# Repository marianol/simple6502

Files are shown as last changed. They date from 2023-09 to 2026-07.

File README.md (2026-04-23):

# simple6502

My own take on a simple 6502 single board computer, inspired on Garth Wilson's excellent 6502 Primer, Daryl Rictor, Ben Eater, and my own beautiful C=64 and all the classic 8-bit computers of the late 70s early 80s.

This project exists because of scope creep on my YAsixfive02 project, which is in its 10000 iteration. Which I don't think will ever end.

## Organization

The project is organized as follows:

- /hardware
    - /simple6502 The SBC computer motherboard a.k.a The Project
    - /IO_Card A 6522 IO card with 2 VIAs
    - /protoCard A protoboard card for the simple6502 to build your projects
    - /6502motherboard An untested but complete card connector backplane motherboard. I decided to abandon this in favor of the SBC, i may pick it up later
    - /schematics PDF schematics and renders
    - /gallery images of the completed PCBs
    - /3dmodels Kicad 3D models
- /firmware
    - BIOS and ROM for the simple6502, check the ReadMe
- /docs
    - docs will be here for now only datasheets 

## Design

The goal is to build a simple 6502 SBC with RAM, ROM, IO decoding and a serial interface. An expansion  bus will carry all the address, data and supporting lines to allow adding IO and other hardware expansions. The PCB will be kept at 100x100mm to reduce cost.

For the serial interface I settled on the Motorola 68B50 ACIA, just because I had one lying around. This forced using a 1.8432MHz clock that drives both the CPU and the ACIA. I added a header for an FTDI card to convert the TTL serial to USB. The ACIA is connected to the IO_8 line locating it at 0x7F70 in the memory map.
The jumper J2 next to the header allows you to run the board with the USB 5v rail from the FTDI. IMPORTANT!! This overrides the power switch SW2 and there is no protection built into the board so you should not connect this jumper at the same time as the 5V barrel J7 or the AUX Power header J8.
The bus Slot connectors have pin 27 tied to IO_1 and IO_2 respectively allowing to design expansion cards that can be mapped into memory based on where they are plugged. You still have access to IO_3 to IO_7 in case you want to use those. The Expansion Port J1 is intended to be used with a 40 pin ribbon for ease of development of prototype boards.

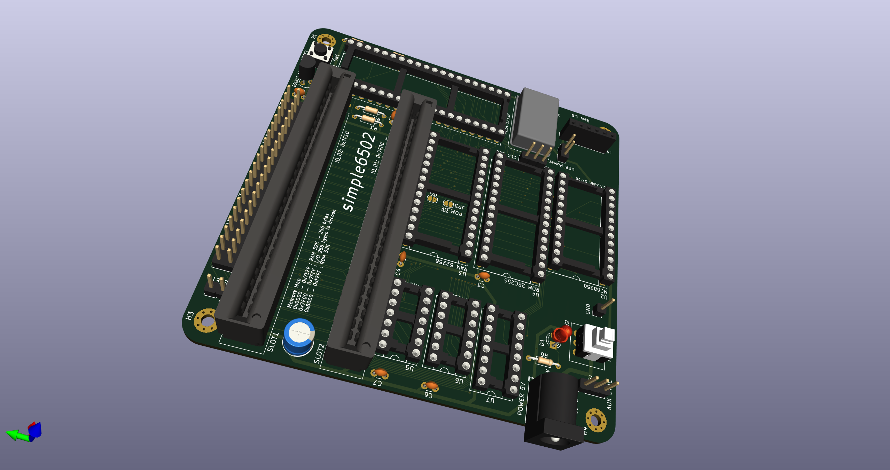
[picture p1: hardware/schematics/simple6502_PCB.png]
Simple6502 Computer


I made the PCBs for Revision 1.6 on PCBWay. 
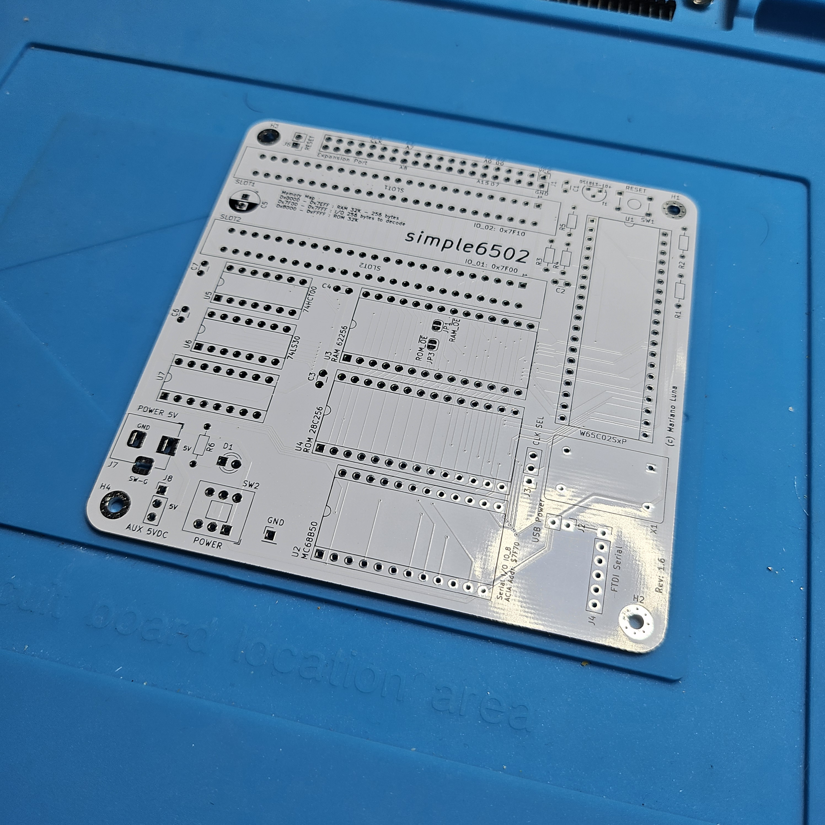
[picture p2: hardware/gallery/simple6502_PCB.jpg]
Simple6502 PCB


## Status

**Revision 1.6:**

- PCB built and tested.
- BIOS 0.0.1 working on Rev 1.6. Minimal BIOS routines to control the ACIA

## Memory Map

Momory Decocing is done using gates for RAM, ROM and IO. IO_CS line is sent to a 3-8 decoder to get 8 individual IO select lines.
IO line  $\overline{IO\textunderscore08}$ is used for the onboard ACIA for serial communication.
IO lines  $\overline{IO\textunderscore01}$ and $\overline{IO\textunderscore02}$ are sent to pin 27 of Slot 1 and 2 respectively. This allows cards that use this pin to get mapped to the memory based on the Slot they are inserted.

I should have mapped some IO on Zero Page for ease of programming and fast IO, but that is left for another revision, since is too convoluted with gates and better suited for a PAL/GAL. 

### Address Space

- 0x0000 - 0x7EFF : RAM 32K - 256 bytes (31.75k)
- 0x7F00 - 0x7F0F : IO_1 > SLOT 1
- 0x7F10 - 0x7F1F : IO_2 > SLOT 2
- 0x7F20 - 0x7F2F : IO_3
- 0x7F30 - 0x7F3F : IO_4
- 0x7F40 - 0x7F4F : IO_5
- 0x7F50 - 0x7F5F : IO_6
- 0x7F60 - 0x7F6F : IO_7
- 0x7F70 - 0x7F7F : IO_8 > ACIA
- 0x7F80 - 0x7FFF : Not Decoded
- 0x8000 - 0xFFFF : ROM (32K)

## Card Connector Design

The card connector is based on the EDAC 395 series. I decided on the 395-50-520-201 which I had from a previous Apple ][ repair.
Exposed in the connector are:

- Address lines A0..A15
- Data lines D0..D7
- Clock $\phi$ 2
- $\overline{IO{\textunderscore}CS}$, $\overline{RAM{\textunderscore}CS}$ , and $\overline{ROM{\textunderscore}CS}$ chip select lines
- $\overline{RD}$ and $\overline{WR}$ 
- $\overline{RESET}$
- Pin 27 is the slot IO select line. For Slot 1 is $\overline{IO\textunderscore01}$ mapping it to 0x7F00, and for Slot 2 is $\overline{IO\textunderscore02}$ mapping it to 0x7F10.
- IO chip select lines $\overline{IO\textunderscore03}$ .. $\overline{IO\textunderscore07}$.
- $\overline{IRQ}$ and $\overline{NMI}$
- VCC and GND, this are set so if you insert a card backwards you will not short them.
- Pins 21, 24, 33, and 34 are only connected between the 2 slots and have no connection to the mainboard 

## Licence

Licenced under CERN Open Hardware licence CERN-OHL-S v2, see CERN-OHL-S-v2.txt

(c) 2023-2024 Mariano Luna. All rights reserved

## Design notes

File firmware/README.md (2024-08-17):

# simple6502 Firmware

This is a BIOS for the simple6502 SBC.

## Requirements

- [x] Serial (ACIA): routines to initialize and manage the serial port.
- [ ] VIA helper routines to interface with a 6522 for I/O
- [x] Memory Monitor: WozMon, why innovate?
- [ ] BASIC: will start with MS Basic from 1976 to be period correct. As a bonus I will have Woz and Gates code in the same ROM
- [ ] Some LOAD/SAVE feature to put binaries in memory though serial/SD for testing. Maybe as an update to WozMon??
- [ ] SPI Interface with VIA (in IO Card)
- [ ] SD Card using SPI

Will come up with some other stuff with 32K I have space for stuff.

## Status

**Version 0.1.0:**

- Tested and working in board rev 1.6
- Features:
  - Wozmon
  - Serial IO Routines

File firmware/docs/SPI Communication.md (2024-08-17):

# SPI Communications

Most of this data comes from:

- <http://elm-chan.org/docs/mmc/mmc_e.html>
- <https://chlazza.nfshost.com/sdcardinfo.html>

## SD Commands

All data sent through the SPI bus are built around the byte - some items may have padding, but the host and card will alwasy send/recieve some multiple of 8 bits.
All command tokens are six bytes long. The card will always respond to every command token with a response token of some kind.

| Command Index | Argument | Response | Data | Abbreviation | Description
| --- | --- | --- | --- | --- | --- | --- |
| CMD0 | None(0) | R1 | No | GO_IDLE_STATE | Software reset.
| CMD1 | None(0) | R1 | No | SEND_OP_COND | Initiate initialization process.
| ACMD41 <sub>*1</sub>  | <sub>*2</sub> | R1 | No | APP_SEND_OP_COND | For only SDC. Initiate initialization process.
| CMD8 | <sub>*3</sub> | R7 | No | SEND_IF_COND | For only SDC V2. Check voltage range.
| CMD9 | None(0) | R1 | Yes | SEND_CSD | Read CSD register.
| CMD10 | None(0) | R1 | Yes | SEND_CID | Read CID register.
| CMD12 | None(0) | R1b | No | STOP_TRANSMISSION | Stop to read data.
| CMD16 | Block | R1 | No | SET_BLOCKLEN | Change R/W block size. 
| | length[31:0] | | | |
| CMD17 | Address[31:0] | R1 | Yes | READ_SINGLE_BLOCK | Read a block.
| CMD18 | Address[31:0] | R1 | Yes | READ_MULTIPLE_BLOCK | Read multiple blocks.
| CMD23 | Number of | R1 | No | SET_BLOCK_COUNT | For only MMC. Define number of blocks to transfer
| | blocks[15:0] | | | | with next multi-block read/write command.
| ACMD23(*1)  | Number of | R1 | No | SET_WR_BLOCK_ERASE_COUNT | For only SDC. Define number of blocks to pre-erase
| | blocks[22:0]  | | | | with next multi-block write command.
| CMD24 | Address[31:0] | R1 | Yes | WRITE_BLOCK | Write a block.
| CMD25 | Address[31:0] | R1 | Yes | WRITE_MULTIPLE_BLOCK | Write multiple blocks.
| CMD55(*1) | None(0) | R1 | No | APP_CMD | Leading command of ACMD\<n> command.
| CMD58 | None(0) | R3 | No | READ_OCR | Read OCR.

*1: ACMD\<n> means a command sequense of CMD55-CM\<n>.
*2: Rsv(0) [31], HCS[30], Rsv(0) [29:0]
*3: Rsv(0) [31:12], Supply Voltage(1) [11:8], Check Pattern(0xAA) [7:0]

## SPI Response

MMC and SDC
There are some command response formats, R1, R2, R3 and R7, depends on the command index. A byte of response, R1, is returned for most commands. The bit field of the R1 response is shown below, the value 0x00 means successful. When any error occured, corresponding status bit in the response will be set. The R3/R7 response (R1 + trailing 32-bit data) is for only CMD58 and CMD8.

Some commands take a time longer than NCR and it responds R1b. It is an R1 response followed by busy flag (DO is driven to low as long as internal process is in progress). The host controller should wait for end of the process until DO goes high (a 0xFF is received).

### R1

| bit 0 | bit 1 | bit 2 | bit 3 | bit 4 | bit 5 | bit 6 | bit 7 |
| --- | --- | --- | --- | --- | --- | --- | --- |
| Always Zero | Parameter Error | Address Error | Erase sequence Error | Command CRC Error | Illegal command | Erase reset | In IDLE state |

### R2

Two bytes in width. The first byte sent is identical to R1. The second byte sent is as follows:

Bit 0: Card is locked > Set when the card is locked by the user. Reset when it is unlocked.
Bit 1: Write protect erase skip | lock/unlock command failed > This status bit has two functions overloaded. It is set when the host attempts to erase a write-protected sector or makes a sequence or password errors during card lock/unlock operation.
Bit 2: Error > A general or an unknown error occurred during the operation.
Bit 3: CC error > Internal card controller error.
Bit 4: Card ECC failed > Card internal ECC was applied but failed to correct the data.
Bit 5: Write protect violation > The command tried to write a write-protected block.
Bit 6: Erase param > An invalid selection for erase, sectors or groups.
Bit 7: out of range | csd overwrite.

### R3

Five bytes in width. The first byte sent is identical to R1. The following four bytes are the contents of the OCR register.

### R7

R7 is 5 bytes long, and the first byte is identical to R1. Following that we have a command version field, a voltage accepted field, and an "echo-back" of the check pattern we sent in the command. Note that if you are using a first generation card, it will only return R1 with the illegal bit command set.

Bit 0-7:   R1 response
Bit 8-11:  Command version
Bit 12-16: Reserved bits
Bit 17-21: Voltage accepted
Bit 22-20: Check pattern

The Voltage accepted pattern is as follows:
0b00000001  Voltage 2.7v to 3.3v
0b00000010  Low Voltage
0b00000100  Reserved
0b00001000  Reserved

Check pattern is an echo of the check pattern

## SD Initialization in SPI mode

<http://elm-chan.org/docs/mmc/mmc_e.html#spiinit>

1. Put thr card in native mode ready for commands, this should be done after
power On or card insertion:

- De-select CS (i.e. make it HIGH)
- Send 10 bytes of 0xFF (i.e. keep MOSI high, toggle CLK 80 times).
  
1. Set SPI mode sending a CMD0 with CS low to reset the card. Since the CMD0 must be sent as a native command, the CRC field must have a valid value.

- Assert CS (set it LOW)
- Send CMD0, then keep reading (by toggling CLK) until a 0x01 response is received

Send a CMD55 (indicates the next byte will be application specific)
Send a CMD41. If the response is not 0 then loop from CMD55 again
Once a zero comes back, the card is ready, send a CMD16 and set block size to 512 bytes

## Block Length

Read and write operations are performed on SD cards in blocks of set lengths. Block length can be set in Standard Capacity SD cards using CMD16 (SET_BLOCKLEN). For SDHC and SDXC cards cards the block length is always set to 512 bytes.

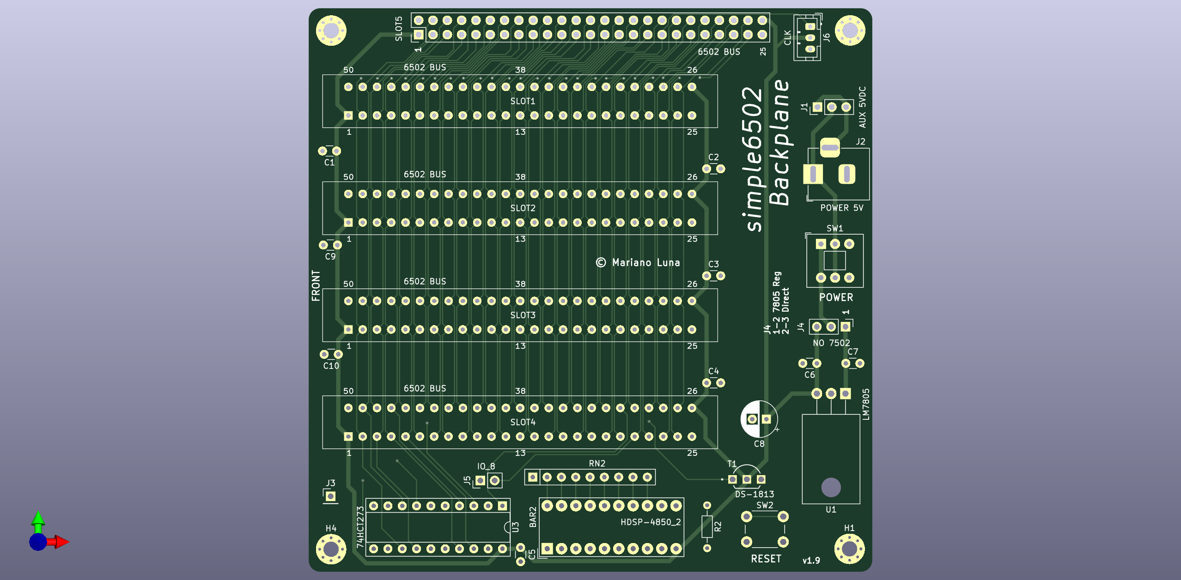
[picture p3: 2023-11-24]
hardware/schematics/6502motherboard_PCB_front_bare.png

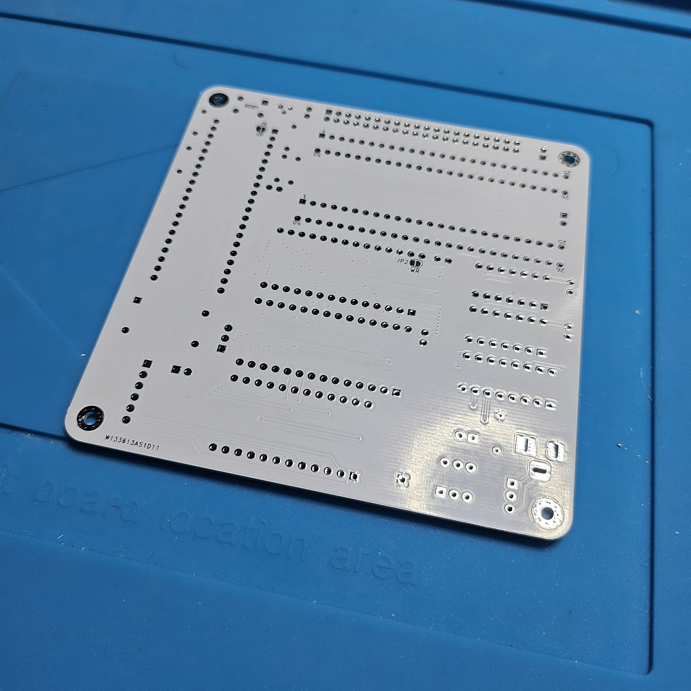
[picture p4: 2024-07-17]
hardware/gallery/simple6502_PCB_back.jpg

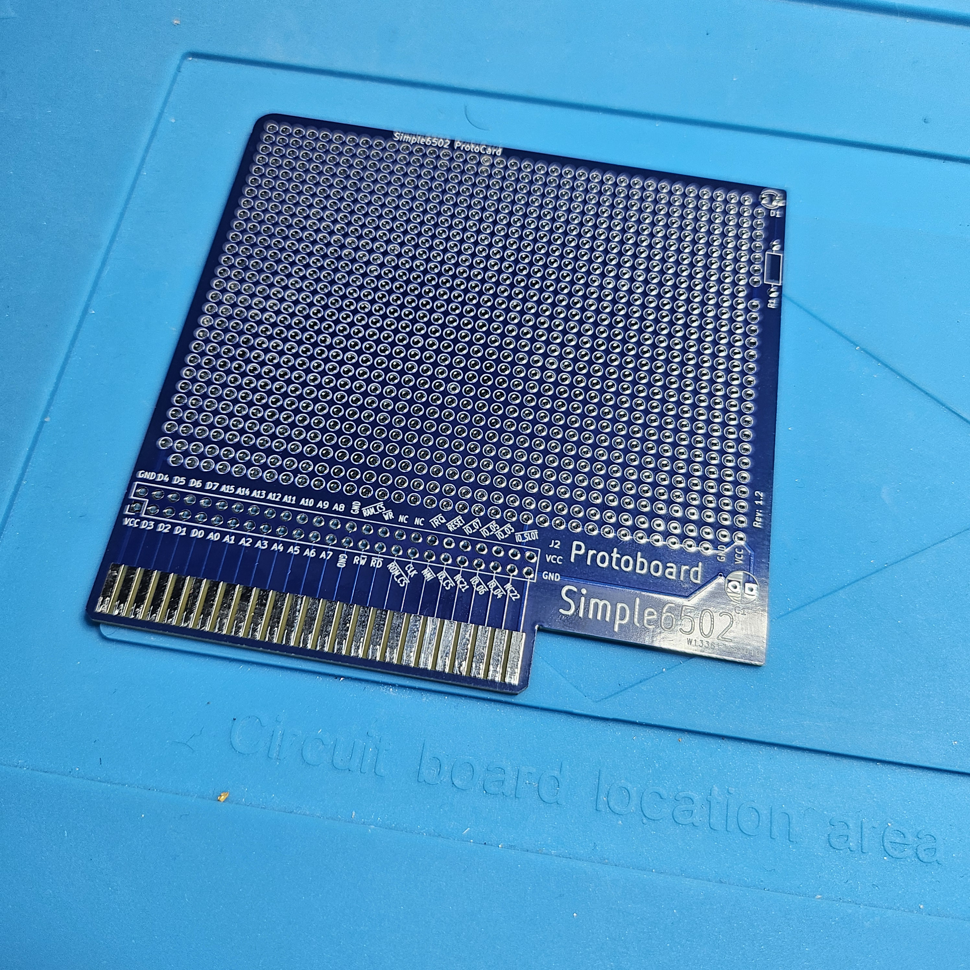
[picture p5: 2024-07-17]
hardware/gallery/protoCard_PCB_front.jpg

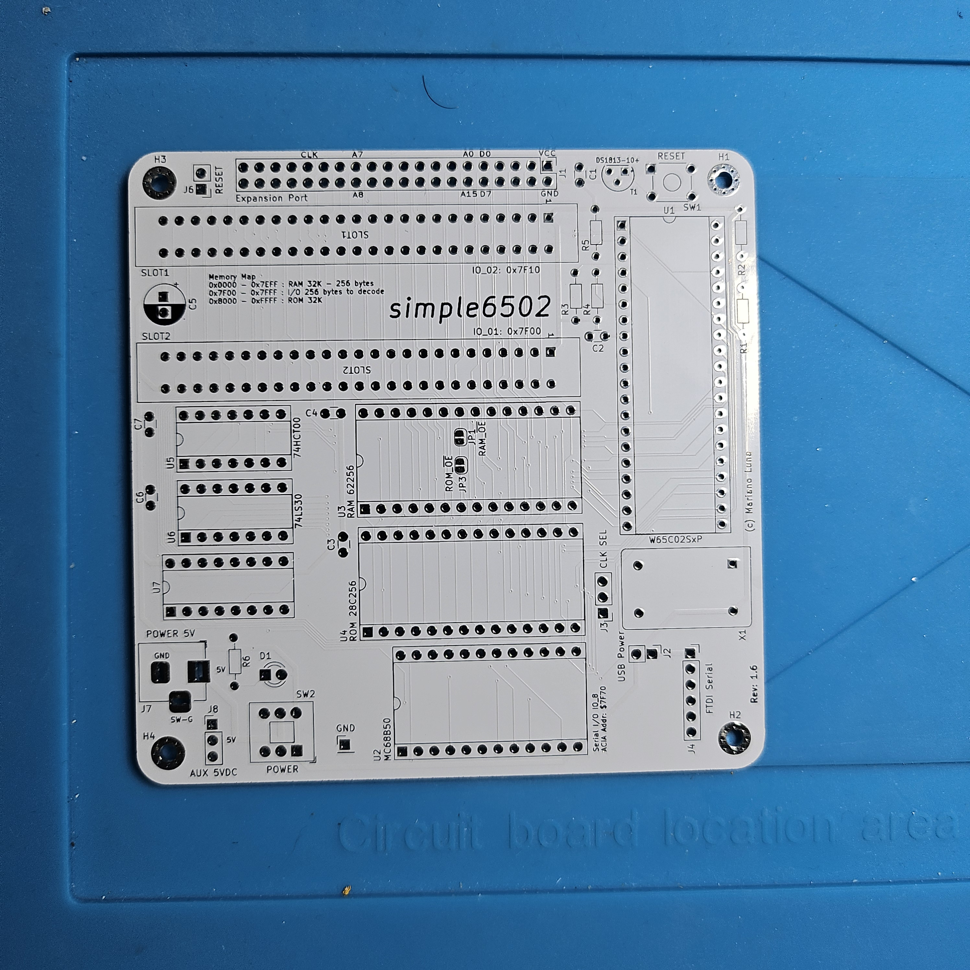
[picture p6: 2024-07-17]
hardware/gallery/simple6502_PCB_front.jpg

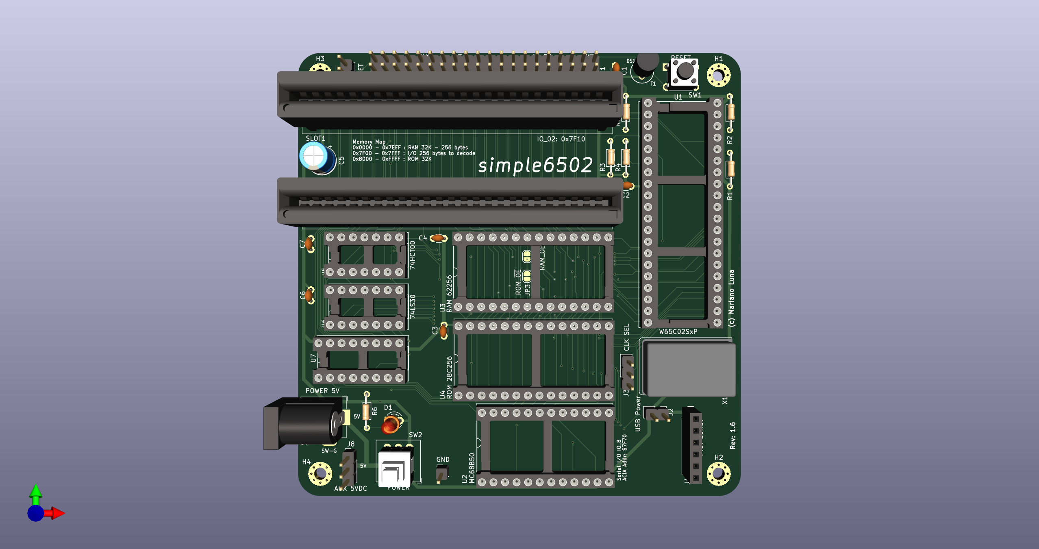
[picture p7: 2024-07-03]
hardware/schematics/simple6502_PCB_front.png

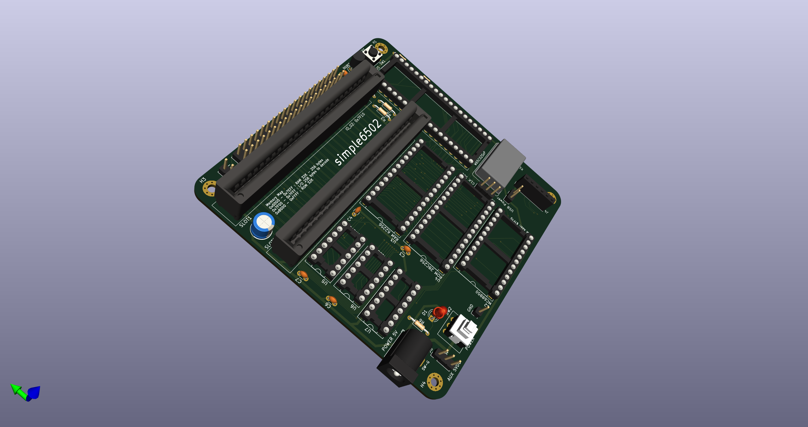
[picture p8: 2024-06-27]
hardware/schematics/simple6502_board.png

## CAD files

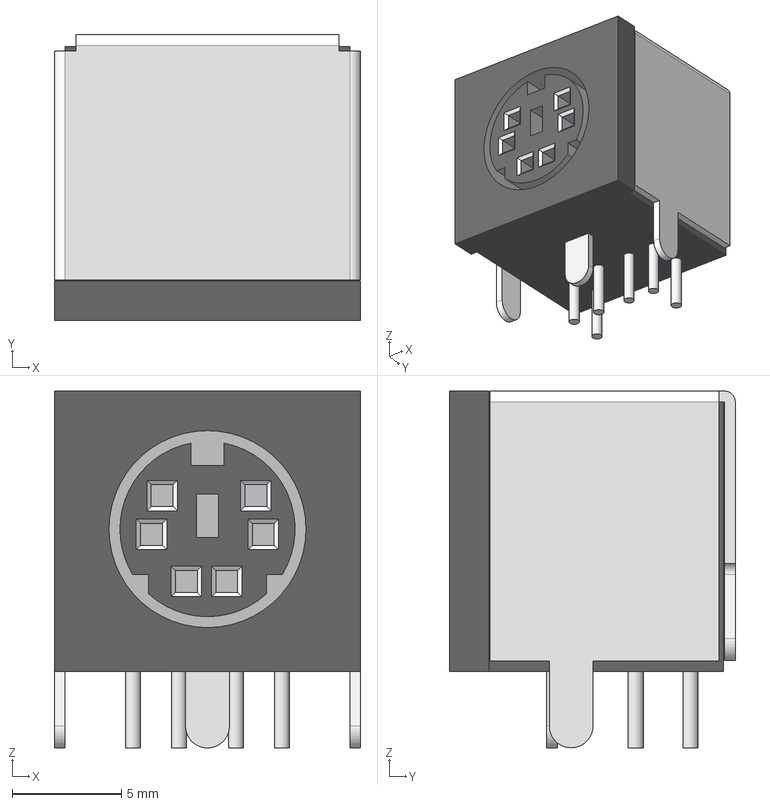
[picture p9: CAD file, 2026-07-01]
hardware/6502_Kicad_Library/3dmodels/Conn_Mini_DIN_round_6_canned.stp
14.0 x 13.1 x 16.3 mm

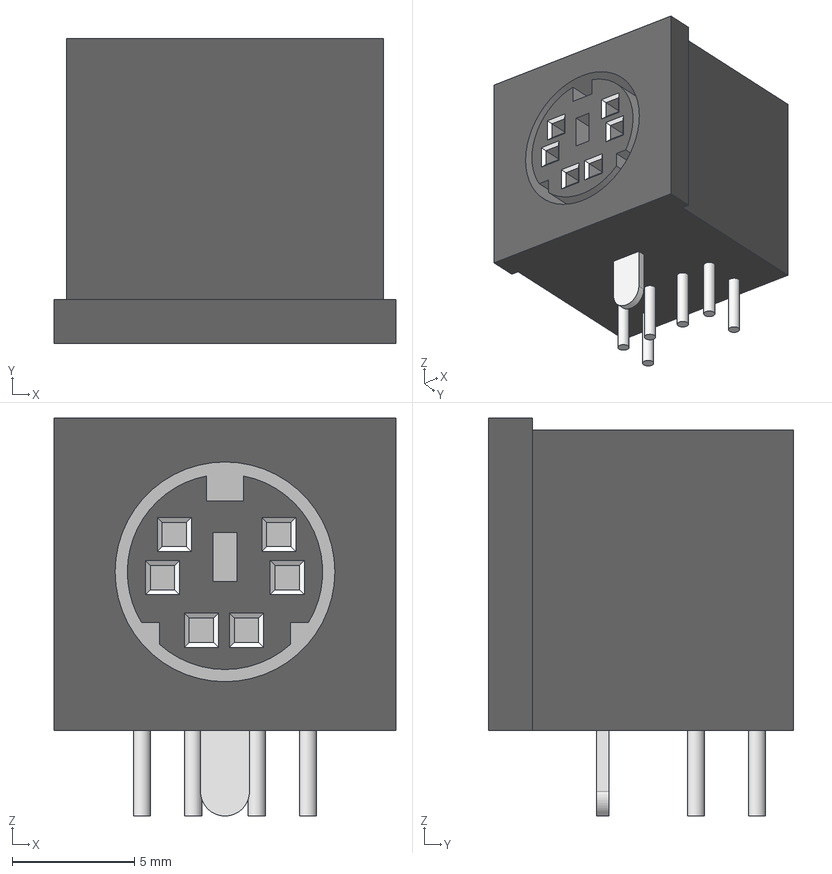
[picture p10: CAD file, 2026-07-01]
hardware/6502_Kicad_Library/3dmodels/Conn_Mini_DIN_round_6.stp
14.0 x 12.5 x 16.3 mm

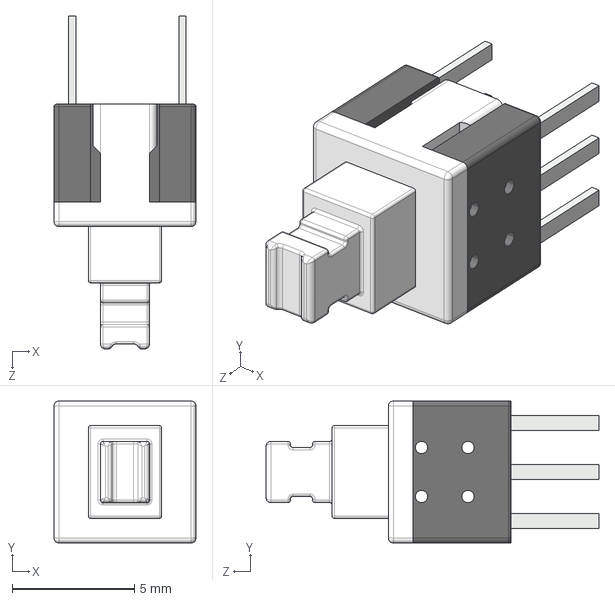
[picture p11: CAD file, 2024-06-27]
hardware/6502_Kicad_Library/3dmodels/5.8x5.8mmSWITCH.STEP
5.80 x 5.80 x 13.6 mm

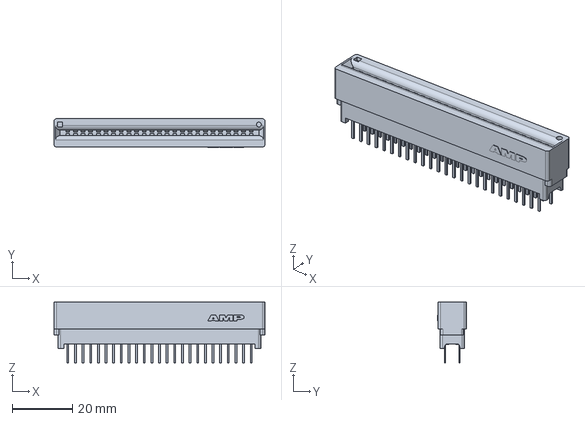
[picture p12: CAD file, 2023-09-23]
hardware/6502_Kicad_Library/3dmodels/CONN 25 POS 2 ROW v2.step
70.1 x 9.47 x 20.2 mm

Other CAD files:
hardware/6502_Kicad_Library/3dmodels/CONN-25POS-2ROW.stl
hardware/6502_Kicad_Library/3dmodels/CONN 25 POS 2 ROW v1.step

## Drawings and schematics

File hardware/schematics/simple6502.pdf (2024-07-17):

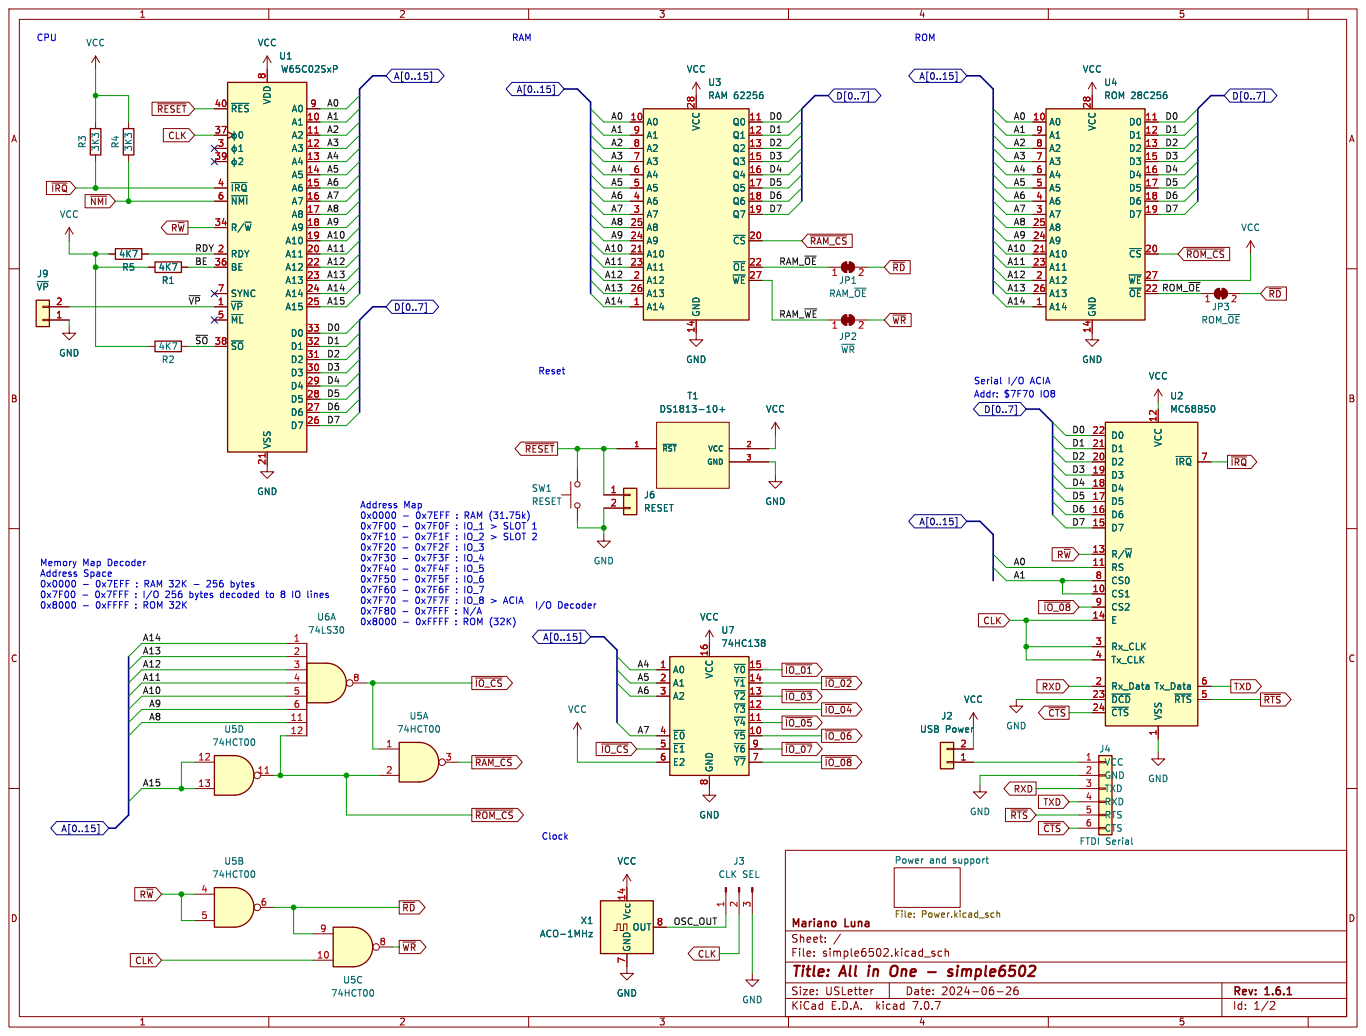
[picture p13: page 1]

Addr: $7F70 IO8 Serial I/O ACIA Clock

I/O Decoder Memory Map Decoder Address Space

0x0000 - 0x7EFF : RAM 32K - 256 bytes 0x7F00 - 0x7FFF : I/O 256 bytes decoded to 8 IO lines 0x8000 - 0xFFFF : ROM 32K

7 OUT X1 8 ACO-1MHz GND GND

Id: 1/2 Title: All in One - simple6502

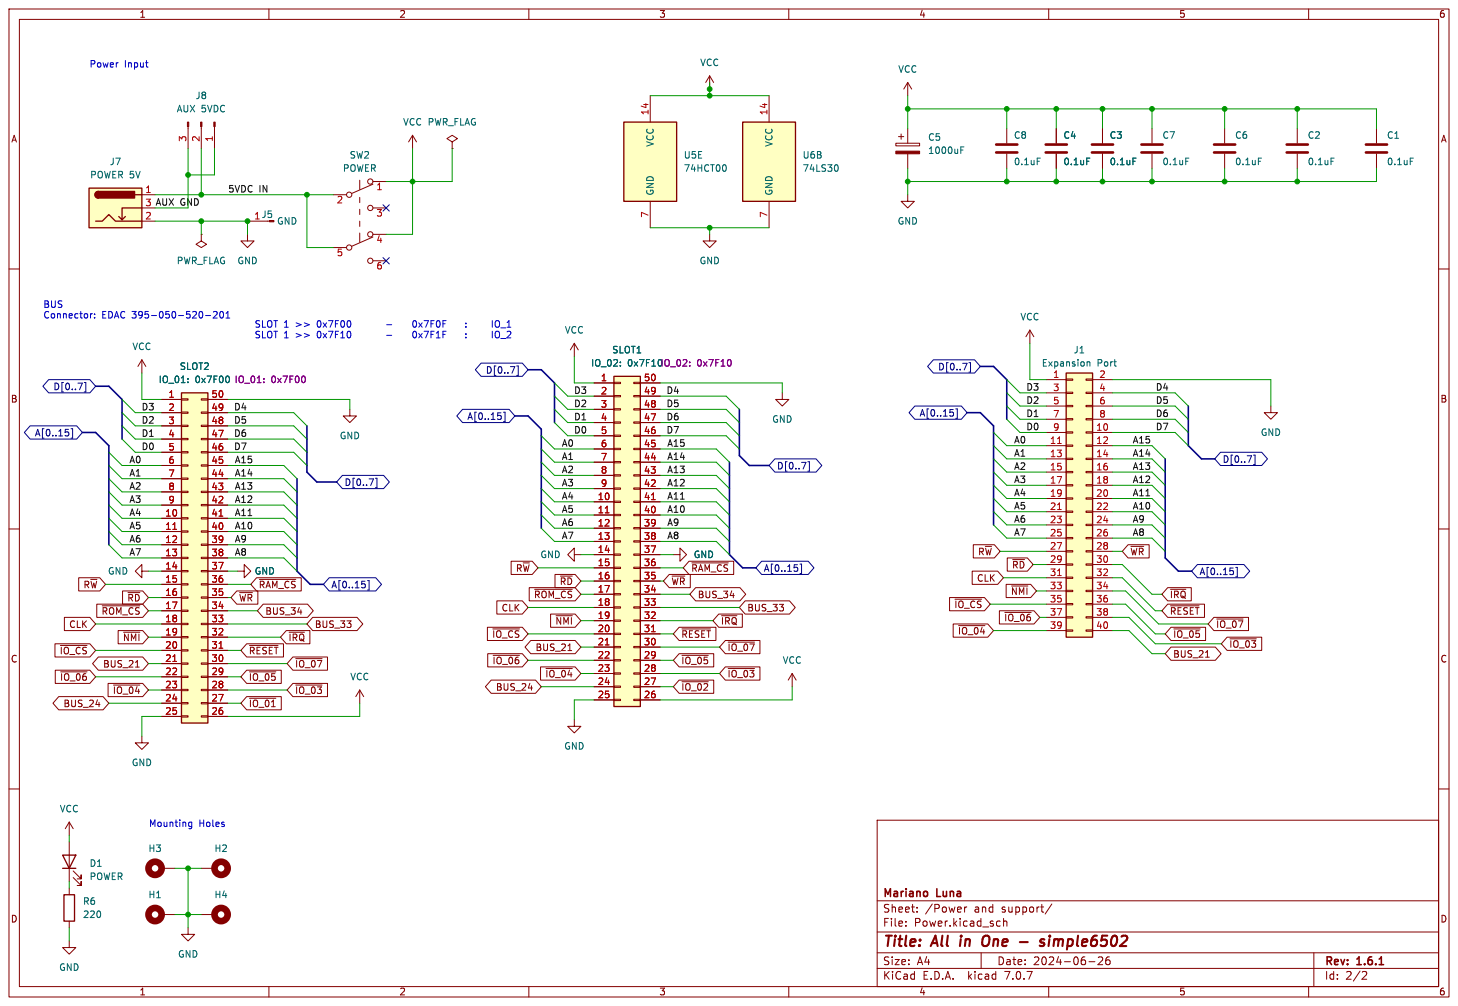
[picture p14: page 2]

J1 Expansion Port VCC GND

Id: 2/2 Title: All in One - simple6502

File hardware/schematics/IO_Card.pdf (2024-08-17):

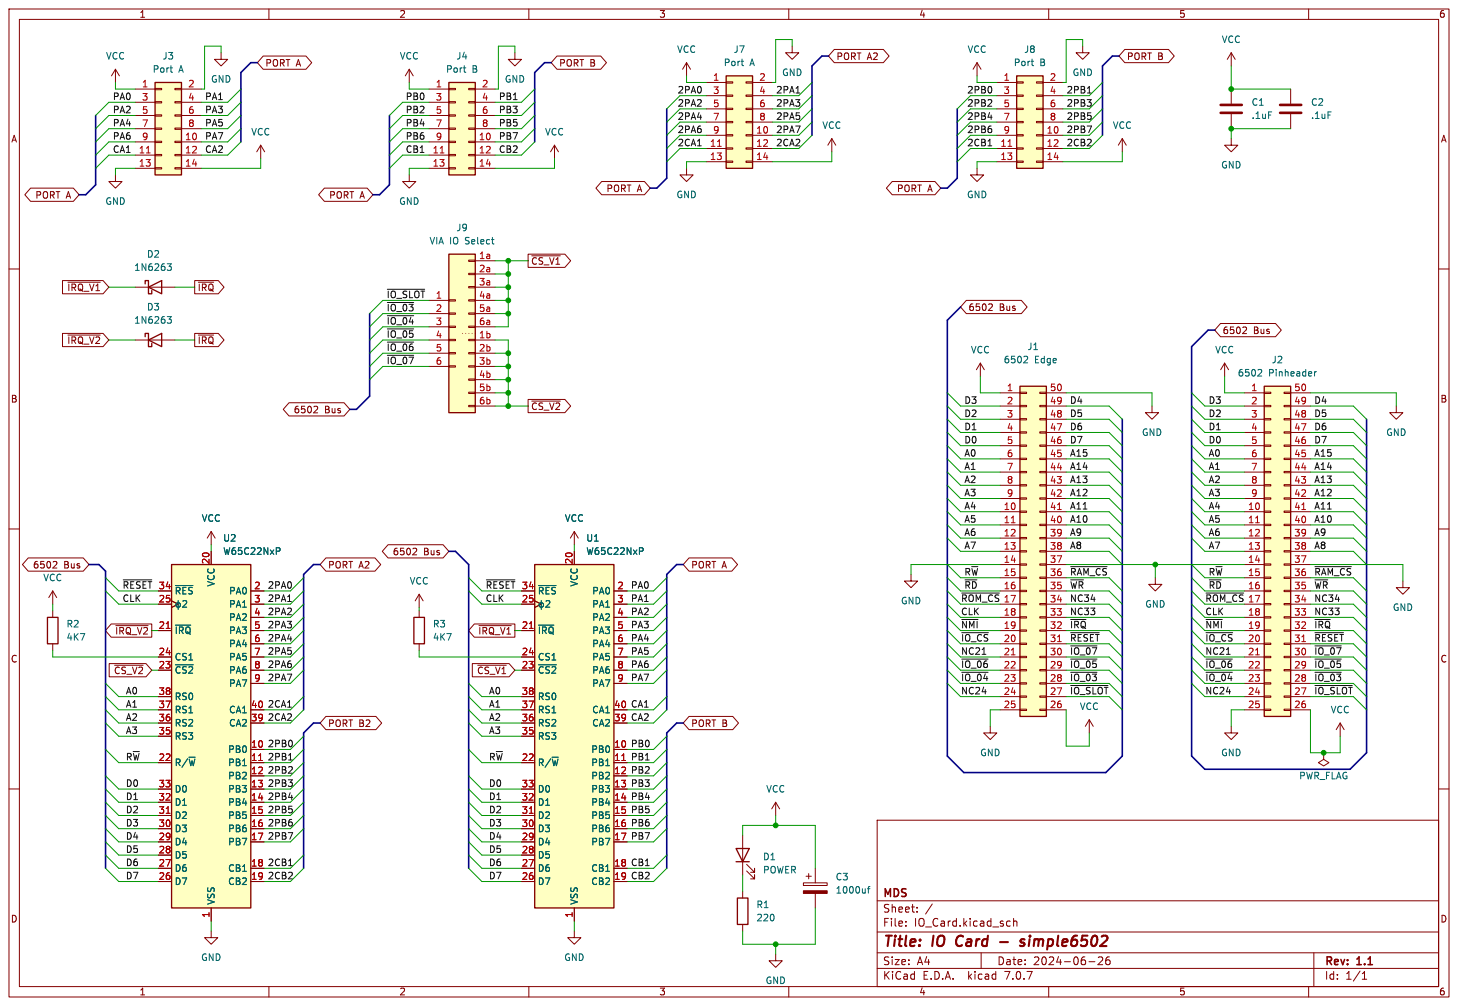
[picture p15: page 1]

Id: 1/1 Title: IO Card - simple6502

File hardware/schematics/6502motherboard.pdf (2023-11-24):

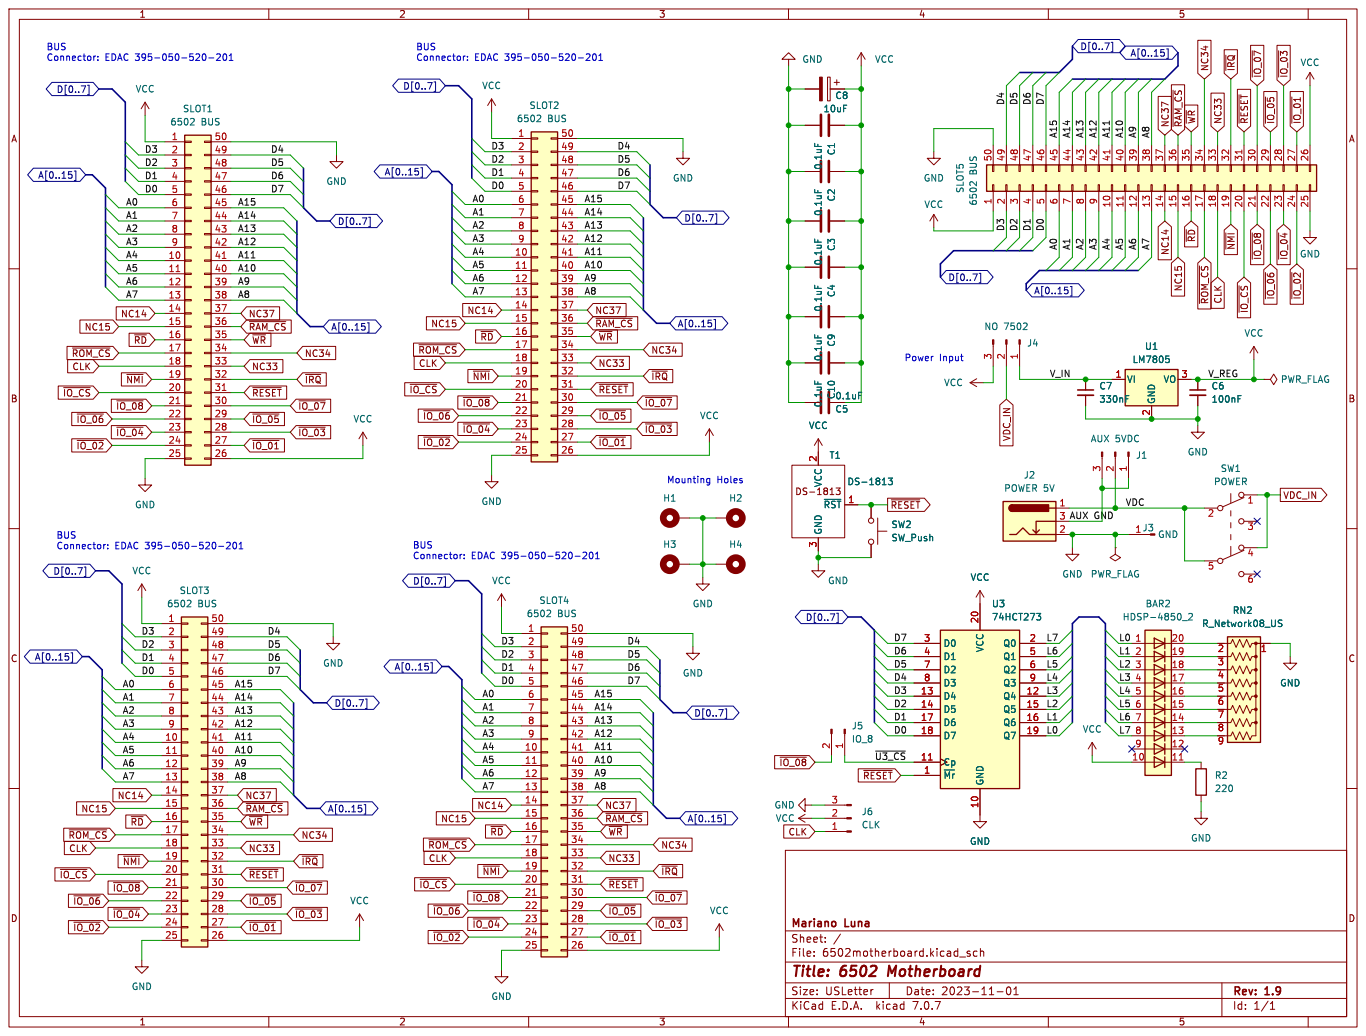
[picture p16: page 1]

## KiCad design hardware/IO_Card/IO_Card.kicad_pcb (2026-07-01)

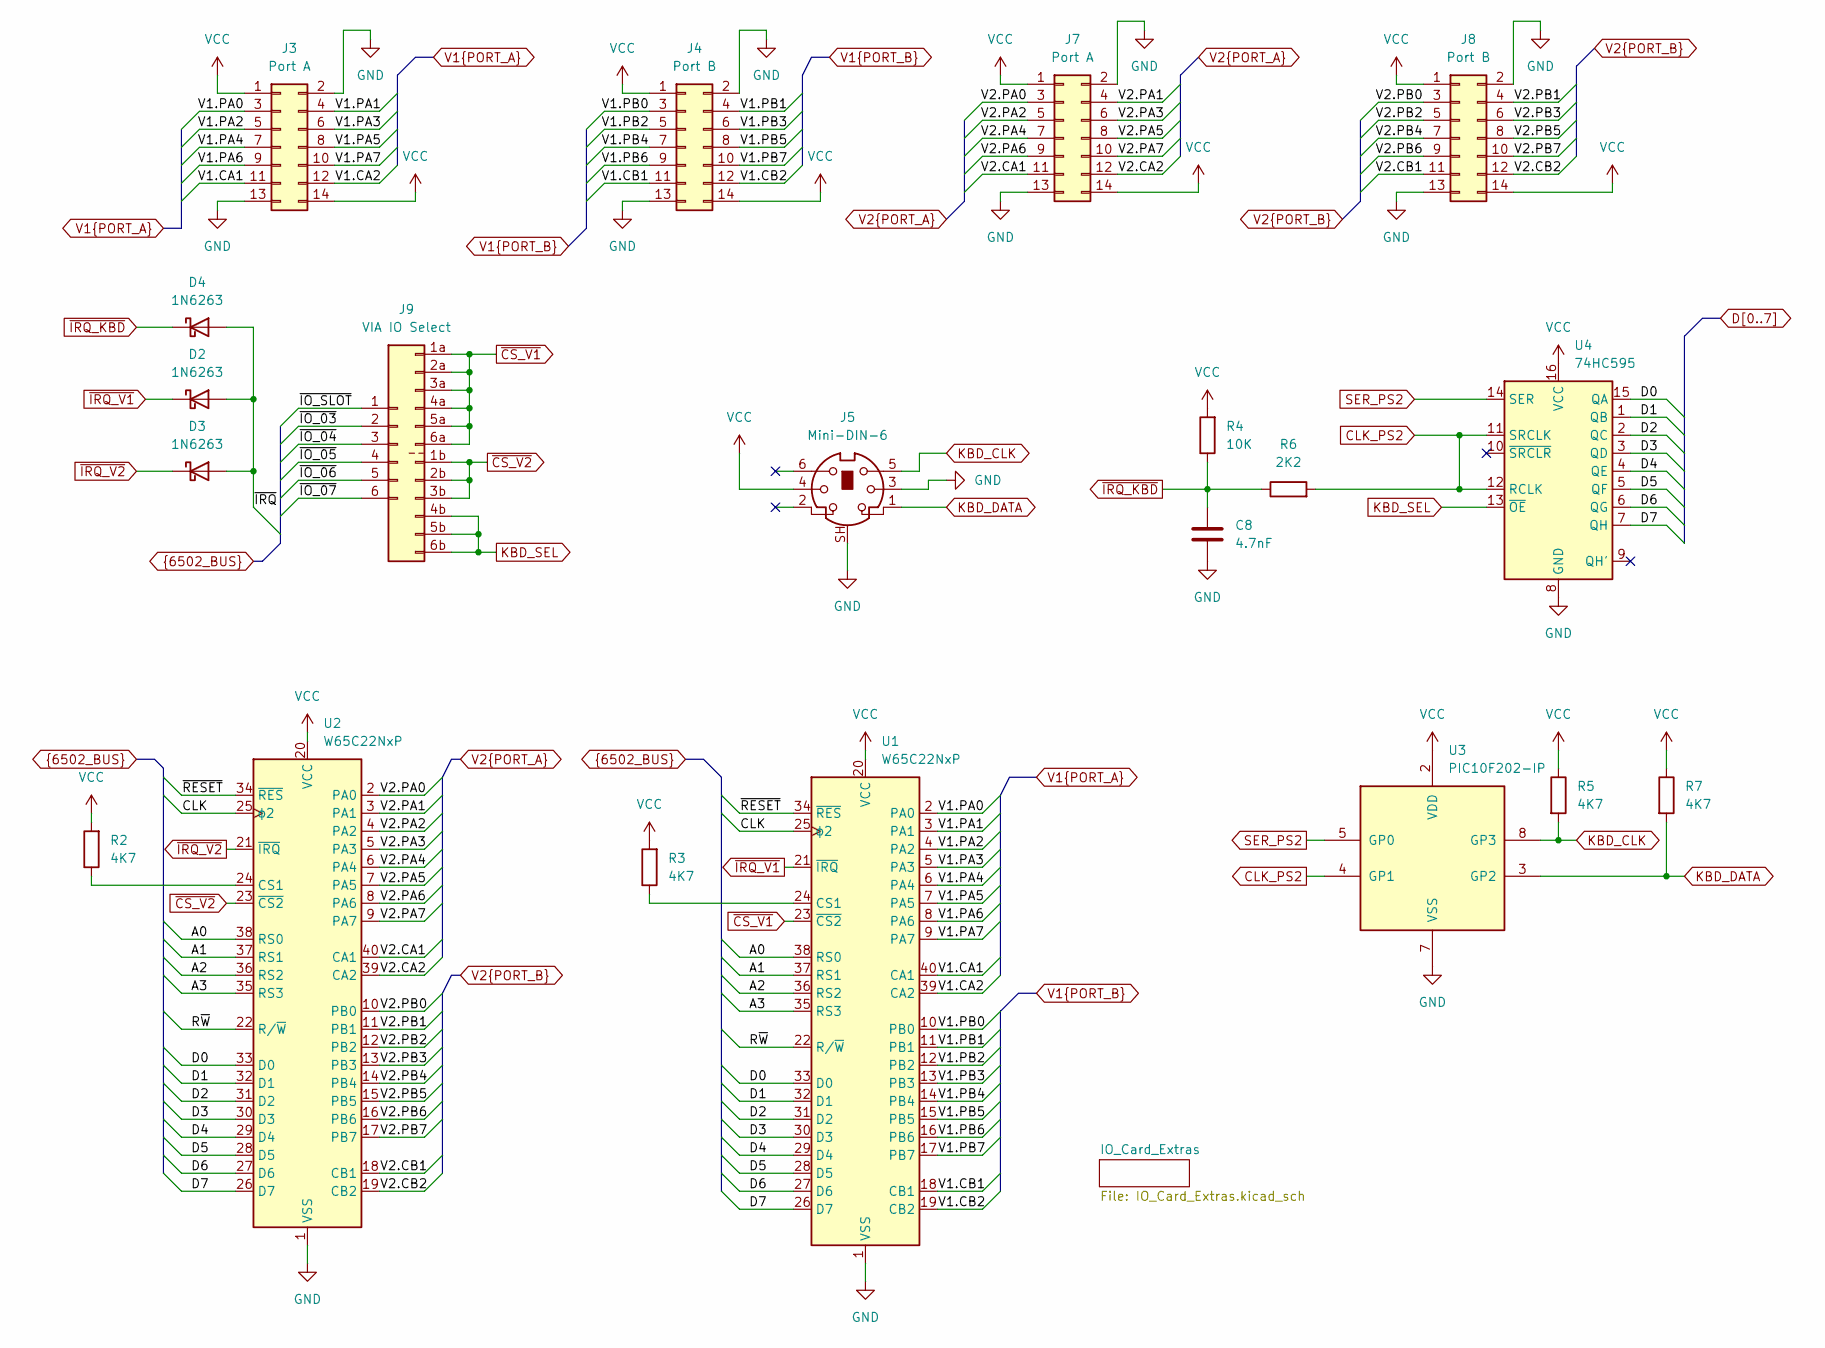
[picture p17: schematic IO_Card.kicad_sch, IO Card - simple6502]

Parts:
C8: 4.7nF; C_Disc_D5.0mm_W2.5mm_P5.00mm
D2, D3, D4: 1N6263; D_DO-35_SOD27_P7.62mm_Horizontal
J3, J7: Port A; PinHeader_2x07_P2.54mm_Horizontal
J4, J8: Port B; PinHeader_2x07_P2.54mm_Horizontal
J5: Mini-DIN-6; J_Mini-DIN-6-Shield
J9: VIA IO Select; PinHeader_3x06_P2.54mm_A_B_Vertical
R2, R3: 4K7; R_Axial_DIN0207_L6.3mm_D2.5mm_P10.16mm_Horizontal
R4: 10K; R_Axial_DIN0207_L6.3mm_D2.5mm_P7.62mm_Horizontal
R5, R7: 4K7; R_Axial_DIN0207_L6.3mm_D2.5mm_P7.62mm_Horizontal
R6: 2K2; R_Axial_DIN0207_L6.3mm_D2.5mm_P7.62mm_Horizontal
U1, U2: W65C22NxP; DIP-40_W15.24mm
U3: PIC10F202-IP; DIP-8_W7.62mm
U4: 74HC595; DIP-16_W7.62mm

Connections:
A0: U1.38 (RS0), U2.38 (RS0); also elsewhere on the board
A1: U1.37 (RS1), U2.37 (RS1); also elsewhere on the board
A2: U1.36 (RS2), U2.36 (RS2); also elsewhere on the board
A3: U1.35 (RS3), U2.35 (RS3); also elsewhere on the board
CLK: U1.25 (ϕ2), U2.25 (ϕ2); also elsewhere on the board
CLK_PS2: R6.2, U3.4 (GP1), U4.11 (SRCLK), U4.12 (RCLK)
D0: U1.33 (D0), U2.33 (D0), U4.15 (QA); also elsewhere on the board
D1: U1.32 (D1), U2.32 (D1), U4.1 (QB); also elsewhere on the board
D2: U1.31 (D2), U2.31 (D2), U4.2 (QC); also elsewhere on the board
D3: U1.30 (D3), U2.30 (D3), U4.3 (QD); also elsewhere on the board
D4: U1.29 (D4), U2.29 (D4), U4.4 (QE); also elsewhere on the board
D5: U1.28 (D5), U2.28 (D5), U4.5 (QF); also elsewhere on the board
D6: U1.27 (D6), U2.27 (D6), U4.6 (QG); also elsewhere on the board
D7: U1.26 (D7), U2.26 (D7), U4.7 (QH); also elsewhere on the board
GND: C8.2, J3.2, J3.13, J4.2, J4.13, J5.3, J5.SH, J7.2, J7.13, J8.2, J8.13, U1.1 (VSS), U2.1 (VSS), U3.7 (VSS), U4.8 (GND); also elsewhere on the board
KBD_CLK: J5.5, R5.2, U3.8 (GP3)
KBD_DATA: J5.1, R7.2, U3.3 (GP2)
KBD_SEL: J9.4b, J9.5b, J9.6b, U4.13 (~OE)
unnamed: R3.1, U1.24 (CS1)
unnamed: R2.1, U2.24 (CS1)
R~W: U1.22 (R/~W), U2.22 (R/~W); also elsewhere on the board
SER_PS2: U3.5 (GP0), U4.14 (SER)
V1.CA1: J3.11, U1.40 (CA1)
V1.CA2: J3.12, U1.39 (CA2)
V1.CB1: J4.11, U1.18 (CB1)
V1.CB2: J4.12, U1.19 (CB2)
V1.PA0: J3.3, U1.2 (PA0)
V1.PA1: J3.4, U1.3 (PA1)
V1.PA2: J3.5, U1.4 (PA2)
V1.PA3: J3.6, U1.5 (PA3)
V1.PA4: J3.7, U1.6 (PA4)
V1.PA5: J3.8, U1.7 (PA5)
V1.PA6: J3.9, U1.8 (PA6)
V1.PA7: J3.10, U1.9 (PA7)
V1.PB0: J4.3, U1.10 (PB0)
V1.PB1: J4.4, U1.11 (PB1)
V1.PB2: J4.5, U1.12 (PB2)
V1.PB3: J4.6, U1.13 (PB3)
V1.PB4: J4.7, U1.14 (PB4)
V1.PB5: J4.8, U1.15 (PB5)
V1.PB6: J4.9, U1.16 (PB6)
V1.PB7: J4.10, U1.17 (PB7)
V2.CA1: J7.11, U2.40 (CA1)
V2.CA2: J7.12, U2.39 (CA2)
V2.CB1: J8.11, U2.18 (CB1)
V2.CB2: J8.12, U2.19 (CB2)
V2.PA0: J7.3, U2.2 (PA0)
V2.PA1: J7.4, U2.3 (PA1)
V2.PA2: J7.5, U2.4 (PA2)
V2.PA3: J7.6, U2.5 (PA3)
V2.PA4: J7.7, U2.6 (PA4)
V2.PA5: J7.8, U2.7 (PA5)
V2.PA6: J7.9, U2.8 (PA6)
V2.PA7: J7.10, U2.9 (PA7)
V2.PB0: J8.3, U2.10 (PB0)
V2.PB1: J8.4, U2.11 (PB1)
V2.PB2: J8.5, U2.12 (PB2)
V2.PB3: J8.6, U2.13 (PB3)
V2.PB4: J8.7, U2.14 (PB4)
V2.PB5: J8.8, U2.15 (PB5)
V2.PB6: J8.9, U2.16 (PB6)
V2.PB7: J8.10, U2.17 (PB7)
VCC: J3.1, J3.14, J4.1, J4.14, J5.4, J7.1, J7.14, J8.1, J8.14, R2.2, R3.2, R4.2, R5.1, R7.1, U1.20 (VCC), U2.20 (VCC), U3.2 (VDD), U4.16 (VCC); also elsewhere on the board
~CS_V1: J9.1a, J9.2a, J9.3a, J9.4a, J9.5a, J9.6a, U1.23 (~CS2)
~CS_V2: J9.1b, J9.2b, J9.3b, U2.23 (~CS2)
~IO_03: J9.2; also elsewhere on the board
~IO_04: J9.3; also elsewhere on the board
~IO_05: J9.4; also elsewhere on the board
~IO_06: J9.5; also elsewhere on the board
~IO_07: J9.6; also elsewhere on the board
~IO_SLOT: J9.1; also elsewhere on the board
~IRQ_KBD: C8.1, D4.1 (K), R4.1, R6.1
~IRQ_V1: D2.1 (K), U1.21 (~IRQ)
~IRQ_V2: D3.1 (K), U2.21 (~IRQ)
~IRQ: D2.2 (A), D3.2 (A), D4.2 (A); also elsewhere on the board
~RESET: U1.34 (~RES), U2.34 (~RES); also elsewhere on the board

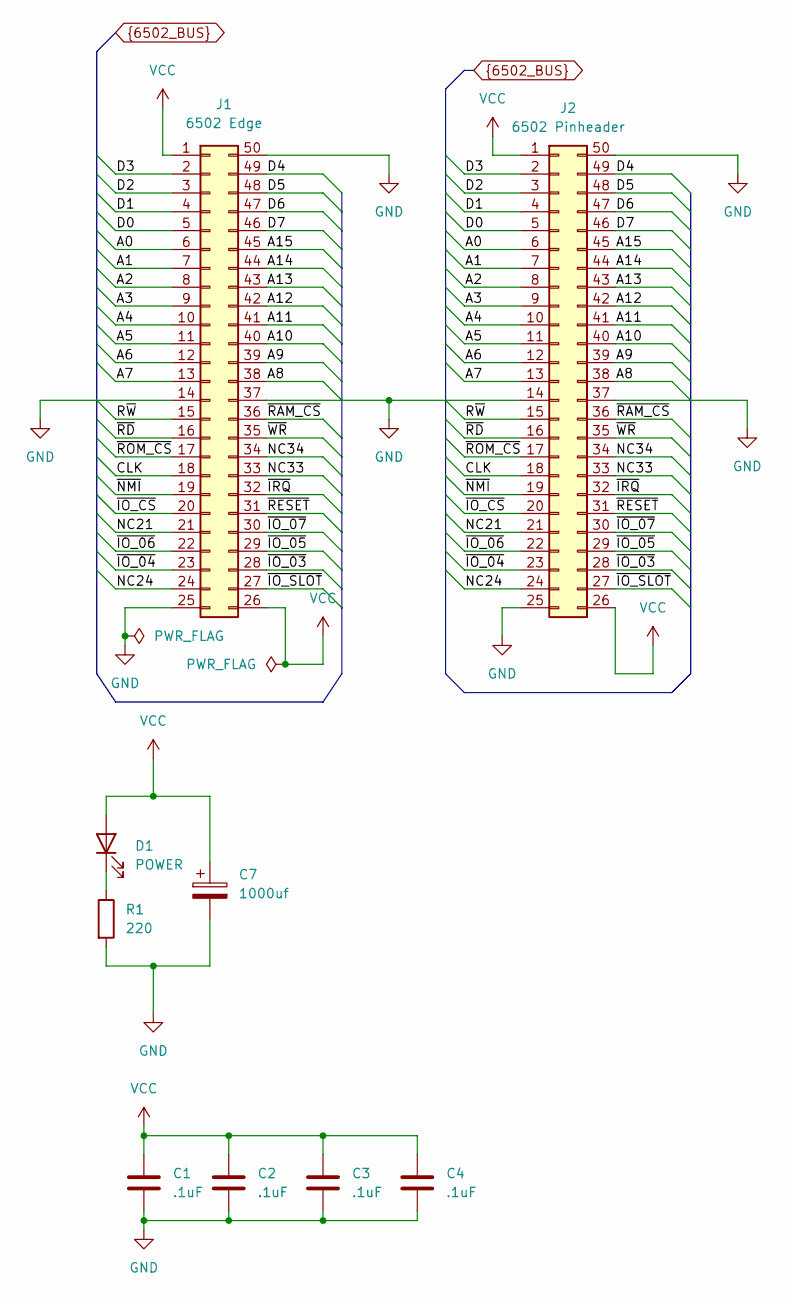
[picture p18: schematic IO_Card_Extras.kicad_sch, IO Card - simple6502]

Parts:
C1, C2, C3, C4: .1uF; C_1206_3216Metric_Pad1.33x1.80mm_HandSolder
C7: 1000uf; CP_Radial_D5.0mm_P2.50mm
D1: POWER; LED_D3.0mm
J1: 6502 Edge; BUS_EdgePCB_Apple_2
J2: 6502 Pinheader; PinHeader_2x25_P2.54mm_Vertical_CounterClockWise
R1: 220; R_Axial_DIN0207_L6.3mm_D2.5mm_P10.16mm_Horizontal

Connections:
A0: J1.6, J2.6; also elsewhere on the board
A1: J1.7, J2.7; also elsewhere on the board
A2: J1.8, J2.8; also elsewhere on the board
A3: J1.9, J2.9; also elsewhere on the board
A4: J1.10, J2.10
A5: J1.11, J2.11
A6: J1.12, J2.12
A7: J1.13, J2.13
A8: J1.38, J2.38
A9: J1.39, J2.39
A10: J1.40, J2.40
A11: J1.41, J2.41
A12: J1.42, J2.42
A13: J1.43, J2.43
A14: J1.44, J2.44
A15: J1.45, J2.45
CLK: J1.18, J2.18; also elsewhere on the board
D0: J1.5, J2.5; also elsewhere on the board
D1: J1.4, J2.4; also elsewhere on the board
D2: J1.3, J2.3; also elsewhere on the board
D3: J1.2, J2.2; also elsewhere on the board
D4: J1.49, J2.49; also elsewhere on the board
D5: J1.48, J2.48; also elsewhere on the board
D6: J1.47, J2.47; also elsewhere on the board
D7: J1.46, J2.46; also elsewhere on the board
GND: C1.2, C2.2, C3.2, C4.2, C7.2, J1.14, J1.25, J1.37, J1.50, J2.14, J2.25, J2.37, J2.50, R1.2; also elsewhere on the board
NC21: J1.21, J2.21
NC24: J1.24, J2.24
NC33: J1.33, J2.33
NC34: J1.34, J2.34
unnamed: D1.1 (K), R1.1
R~W: J1.15, J2.15; also elsewhere on the board
VCC: C1.1, C2.1, C3.1, C4.1, C7.1, D1.2 (A), J1.1, J1.26, J2.1, J2.26; also elsewhere on the board
~IO_03: J1.28, J2.28; also elsewhere on the board
~IO_04: J1.23, J2.23; also elsewhere on the board
~IO_05: J1.29, J2.29; also elsewhere on the board
~IO_06: J1.22, J2.22; also elsewhere on the board
~IO_07: J1.30, J2.30; also elsewhere on the board
~IO_CS: J1.20, J2.20
~IO_SLOT: J1.27, J2.27; also elsewhere on the board
~IRQ: J1.32, J2.32; also elsewhere on the board
~NMI: J1.19, J2.19
~RAM_CS: J1.36, J2.36
~RD: J1.16, J2.16
~RESET: J1.31, J2.31; also elsewhere on the board
~ROM_CS: J1.17, J2.17
~WR: J1.35, J2.35

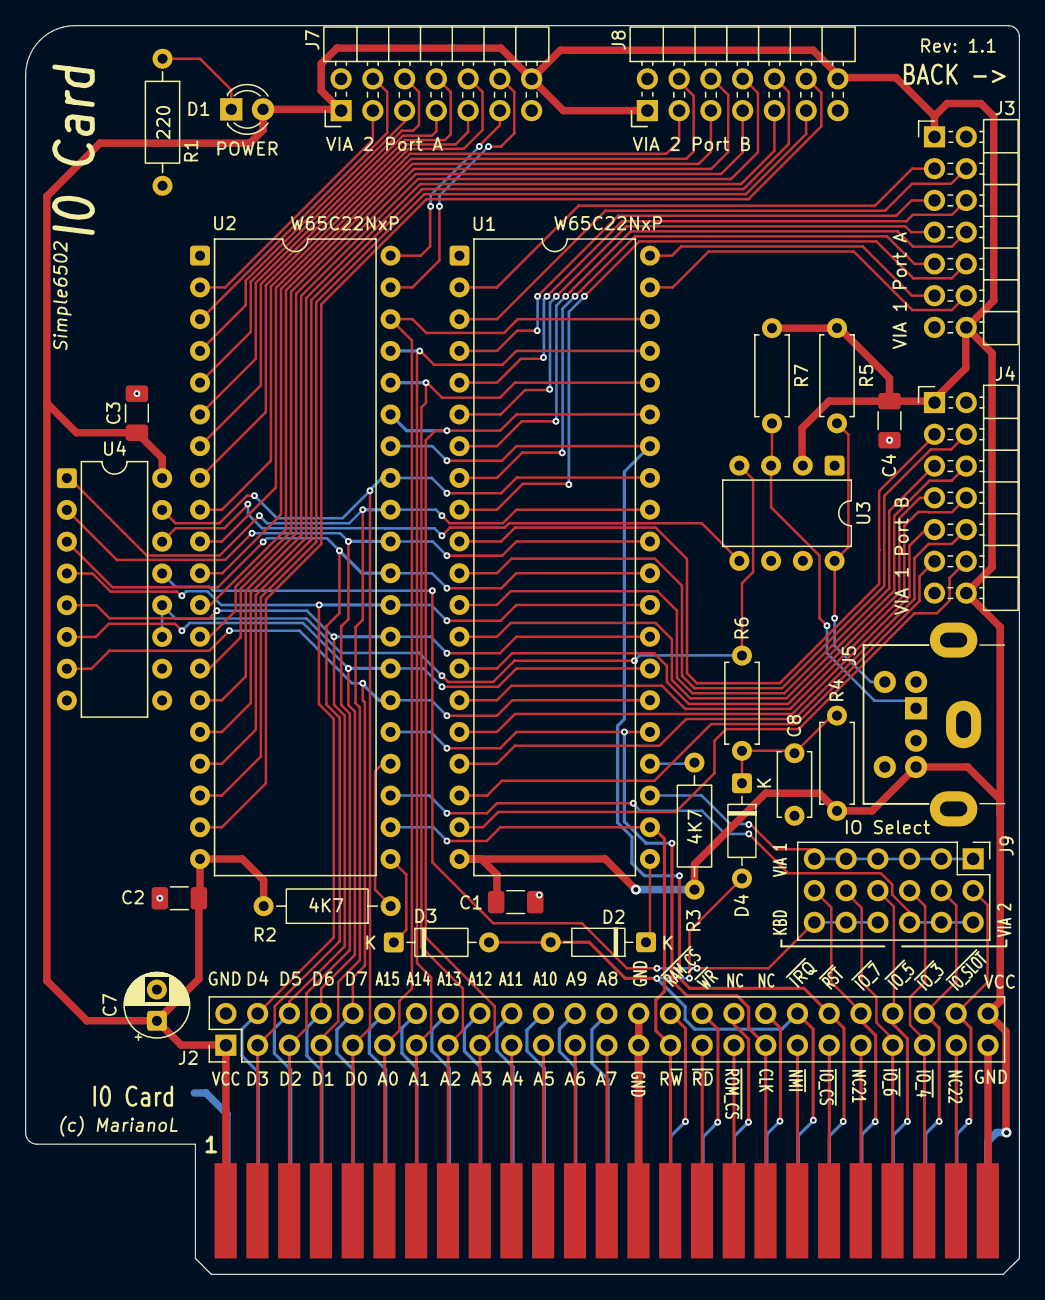
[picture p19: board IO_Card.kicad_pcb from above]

Board: 2 copper layers, 79.5 x 99.9 mm, 29 parts (0 on the bottom side), 99 nets.

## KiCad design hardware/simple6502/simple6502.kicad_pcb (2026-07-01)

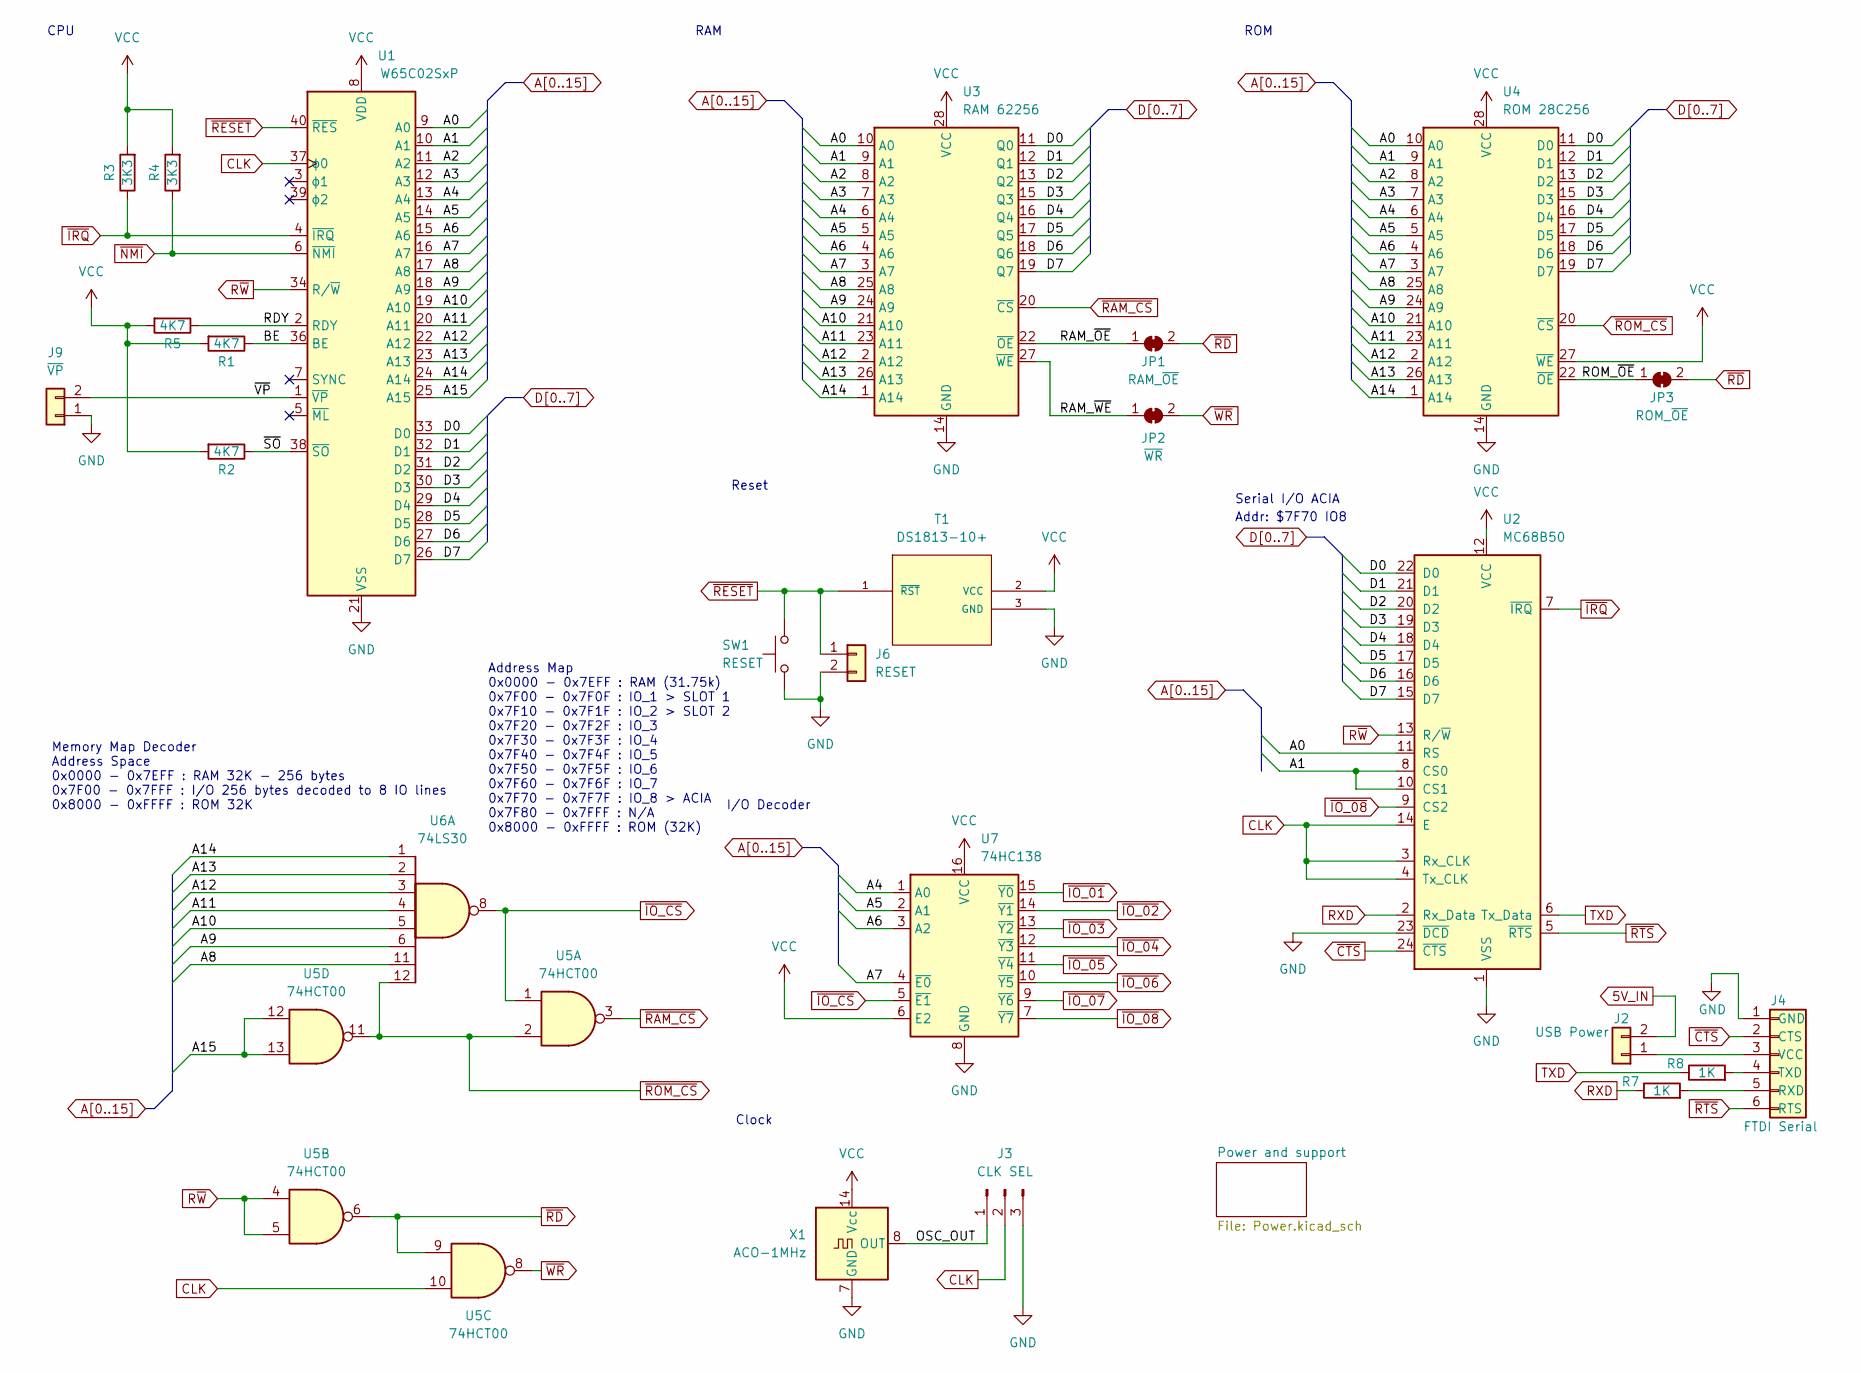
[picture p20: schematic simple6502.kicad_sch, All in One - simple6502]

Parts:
J2: USB Power; PinHeader_1x02_P2.54mm_Vertical
J3: CLK SEL; PinHeader_1x03_P2.54mm_Vertical
J4: FTDI Serial; PinSocket_1x06_P2.54mm_Vertical
J6: RESET; PinHeader_1x02_P2.54mm_Vertical
J9: ~{VP}; SolderJumper-2_P1.3mm_Open_RoundedPad1.0x1.5mm
JP1: RAM_~{OE}; SolderJumper-2_P1.3mm_Bridged_RoundedPad1.0x1.5mm
JP2: ~{WR}; SolderJumper-2_P1.3mm_Bridged_RoundedPad1.0x1.5mm
JP3: ROM_~{OE}; SolderJumper-2_P1.3mm_Bridged_RoundedPad1.0x1.5mm
R1, R2, R5: 4K7; R_Axial_DIN0204_L3.6mm_D1.6mm_P7.62mm_Horizontal
R3, R4: 3K3; R_Axial_DIN0204_L3.6mm_D1.6mm_P7.62mm_Horizontal
R7, R8: 1K; R_Axial_DIN0204_L3.6mm_D1.6mm_P7.62mm_Horizontal
SW1: RESET; SW_TH_Tactile_Omron_B3F-10xx
T1: DS1813-10+; 21-0248A
U1: W65C02SxP; DIP-40_W15.24mm_Socket
U2: MC68B50; DIP-24_W15.24mm_Socket
U3: RAM 62256; DIP-28_W15.24mm_Socket
U4: ROM 28C256; DIP-28_W15.24mm_Socket
U5: 74HCT00; DIP-14_W7.62mm_Socket
U6: 74LS30; DIP-14_W7.62mm_Socket
U7: 74HC138; DIP-16_W7.62mm_Socket
X1: ACO-1MHz; Oscillator_DIP-14

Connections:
5V_IN: J2.2; also elsewhere on the board
/BE: R1.1, U1.36 (BE)
/OSC_OUT: J3.1, X1.8 (OUT)
/RAM_~OE: JP1.1 (A), U3.22 (~OE)
/RAM_~WE: JP2.1 (A), U3.27 (~WE)
/RDY: R5.1, U1.2 (RDY)
/ROM_~OE: JP3.1 (A), U4.22 (~OE)
/~SO: R2.1, U1.38 (~SO)
/~VP: J9.2, U1.1 (~VP)
A0: U1.9 (A0), U2.11 (RS), U3.10 (A0), U4.10 (A0); also elsewhere on the board
A1: U1.10 (A1), U2.8 (CS0), U2.10 (CS1), U3.9 (A1), U4.9 (A1); also elsewhere on the board
A2: U1.11 (A2), U3.8 (A2), U4.8 (A2); also elsewhere on the board
A3: U1.12 (A3), U3.7 (A3), U4.7 (A3); also elsewhere on the board
A4: U1.13 (A4), U3.6 (A4), U4.6 (A4), U7.1 (A0); also elsewhere on the board
A5: U1.14 (A5), U3.5 (A5), U4.5 (A5), U7.2 (A1); also elsewhere on the board
A6: U1.15 (A6), U3.4 (A6), U4.4 (A6), U7.3 (A2); also elsewhere on the board
A7: U1.16 (A7), U3.3 (A7), U4.3 (A7), U7.4 (~E0); also elsewhere on the board
A8: U1.17 (A8), U3.25 (A8), U4.25 (A8), U6.11; also elsewhere on the board
A9: U1.18 (A9), U3.24 (A9), U4.24 (A9), U6.6; also elsewhere on the board
A10: U1.19 (A10), U3.21 (A10), U4.21 (A10), U6.5; also elsewhere on the board
A11: U1.20 (A11), U3.23 (A11), U4.23 (A11), U6.4; also elsewhere on the board
A12: U1.22 (A12), U3.2 (A12), U4.2 (A12), U6.3; also elsewhere on the board
A13: U1.23 (A13), U3.26 (A13), U4.26 (A13), U6.2; also elsewhere on the board
A14: U1.24 (A14), U3.1 (A14), U4.1 (A14), U6.1; also elsewhere on the board
A15: U1.25 (A15), U5.12, U5.13; also elsewhere on the board
CLK: J3.2, U1.37 (ϕ0), U2.3 (Rx_CLK), U2.4 (Tx_CLK), U2.14 (E), U5.10; also elsewhere on the board
D0: U1.33 (D0), U2.22 (D0), U3.11 (Q0), U4.11 (D0); also elsewhere on the board
D1: U1.32 (D1), U2.21 (D1), U3.12 (Q1), U4.12 (D1); also elsewhere on the board
D2: U1.31 (D2), U2.20 (D2), U3.13 (Q2), U4.13 (D2); also elsewhere on the board
D3: U1.30 (D3), U2.19 (D3), U3.15 (Q3), U4.15 (D3); also elsewhere on the board
D4: U1.29 (D4), U2.18 (D4), U3.16 (Q4), U4.16 (D4); also elsewhere on the board
D5: U1.28 (D5), U2.17 (D5), U3.17 (Q5), U4.17 (D5); also elsewhere on the board
D6: U1.27 (D6), U2.16 (D6), U3.18 (Q6), U4.18 (D6); also elsewhere on the board
D7: U1.26 (D7), U2.15 (D7), U3.19 (Q7), U4.19 (D7); also elsewhere on the board
GND: J3.3, J4.1 (GND), J6.2, J9.1, SW1.1, T1.3 (GND), U1.21 (VSS), U2.1 (VSS), U2.23 (~DCD), U3.14 (GND), U4.14 (GND), U7.8 (GND), X1.7 (GND); also elsewhere on the board
unnamed: J2.1, J4.3 (VCC)
unnamed: J4.5 (RXD), R7.2
unnamed: J4.4 (TXD), R8.2
RXD: R7.1, U2.2 (Rx_Data)
R~W: U1.34 (R/~W), U2.13 (R/~W), U5.4, U5.5; also elsewhere on the board
TXD: R8.1, U2.6 (Tx_Data)
VCC: R1.2, R2.2, R3.2, R4.2, R5.2, T1.2 (VCC), U1.8 (VDD), U2.12 (VCC), U3.28 (VCC), U4.27 (~WE), U4.28 (VCC), U7.6 (E2), U7.16 (VCC), X1.14 (Vcc); also elsewhere on the board
~CTS: J4.2 (CTS), U2.24 (~CTS)
~IO_02: U7.14 (~Y1); also elsewhere on the board
~IO_03: U7.13 (~Y2); also elsewhere on the board
~IO_04: U7.12 (~Y3); also elsewhere on the board
~IO_05: U7.11 (~Y4); also elsewhere on the board
~IO_06: U7.10 (~Y5); also elsewhere on the board
~IO_07: U7.9 (~Y6); also elsewhere on the board
~IO_08: U2.9 (CS2), U7.7 (~Y7)
~IO_CS: U5.1, U6.8, U7.5 (~E1); also elsewhere on the board
~IRQ: R3.1, U1.4 (~IRQ), U2.7 (~IRQ); also elsewhere on the board
~NMI: R4.1, U1.6 (~NMI); also elsewhere on the board
~RAM_CS: U3.20 (~CS), U5.3; also elsewhere on the board
~RD: JP1.2 (B), JP3.2 (B), U5.6, U5.9; also elsewhere on the board
~RESET: J6.1, SW1.2, T1.1 (~RST), U1.40 (~RES); also elsewhere on the board
~ROM_CS: U4.20 (~CS), U5.2, U5.11, U6.12; also elsewhere on the board
~RTS: J4.6 (RTS), U2.5 (~RTS)
~WR: JP2.2 (B), U5.8; also elsewhere on the board

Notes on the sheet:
Addr: $7F70 IO8
Reset
Clock
Memory Map Decoder Address Space 0x0000 - 0x7EFF : RAM 32K - 256 bytes 0x7F00 - 0x7FFF : I/O 256 bytes decoded to 8 IO lines 0x8000 - 0xFFFF : ROM 32K
Serial I/O ACIA
RAM
CPU
ROM
Address Map 0x0000 - 0x7EFF : RAM (31.75k) 0x7F00 - 0x7F0F : IO_1 > SLOT 1 0x7F10 - 0x7F1F : IO_2 > SLOT 2 0x7F20 - 0x7F2F : IO_3 0x7F30 - 0x7F3F : IO_4 0x7F40 - 0x7F4F : IO_5 0x7F50 - 0x7F5F : IO_6 0x7F60 - 0x7F6F : IO_7 0x7F70 - 0x7F7F : IO_8 > ACIA 0x7F80 - 0x7FFF : N/A 0x8000 - 0xFFFF : ROM (32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
I/O Decoder

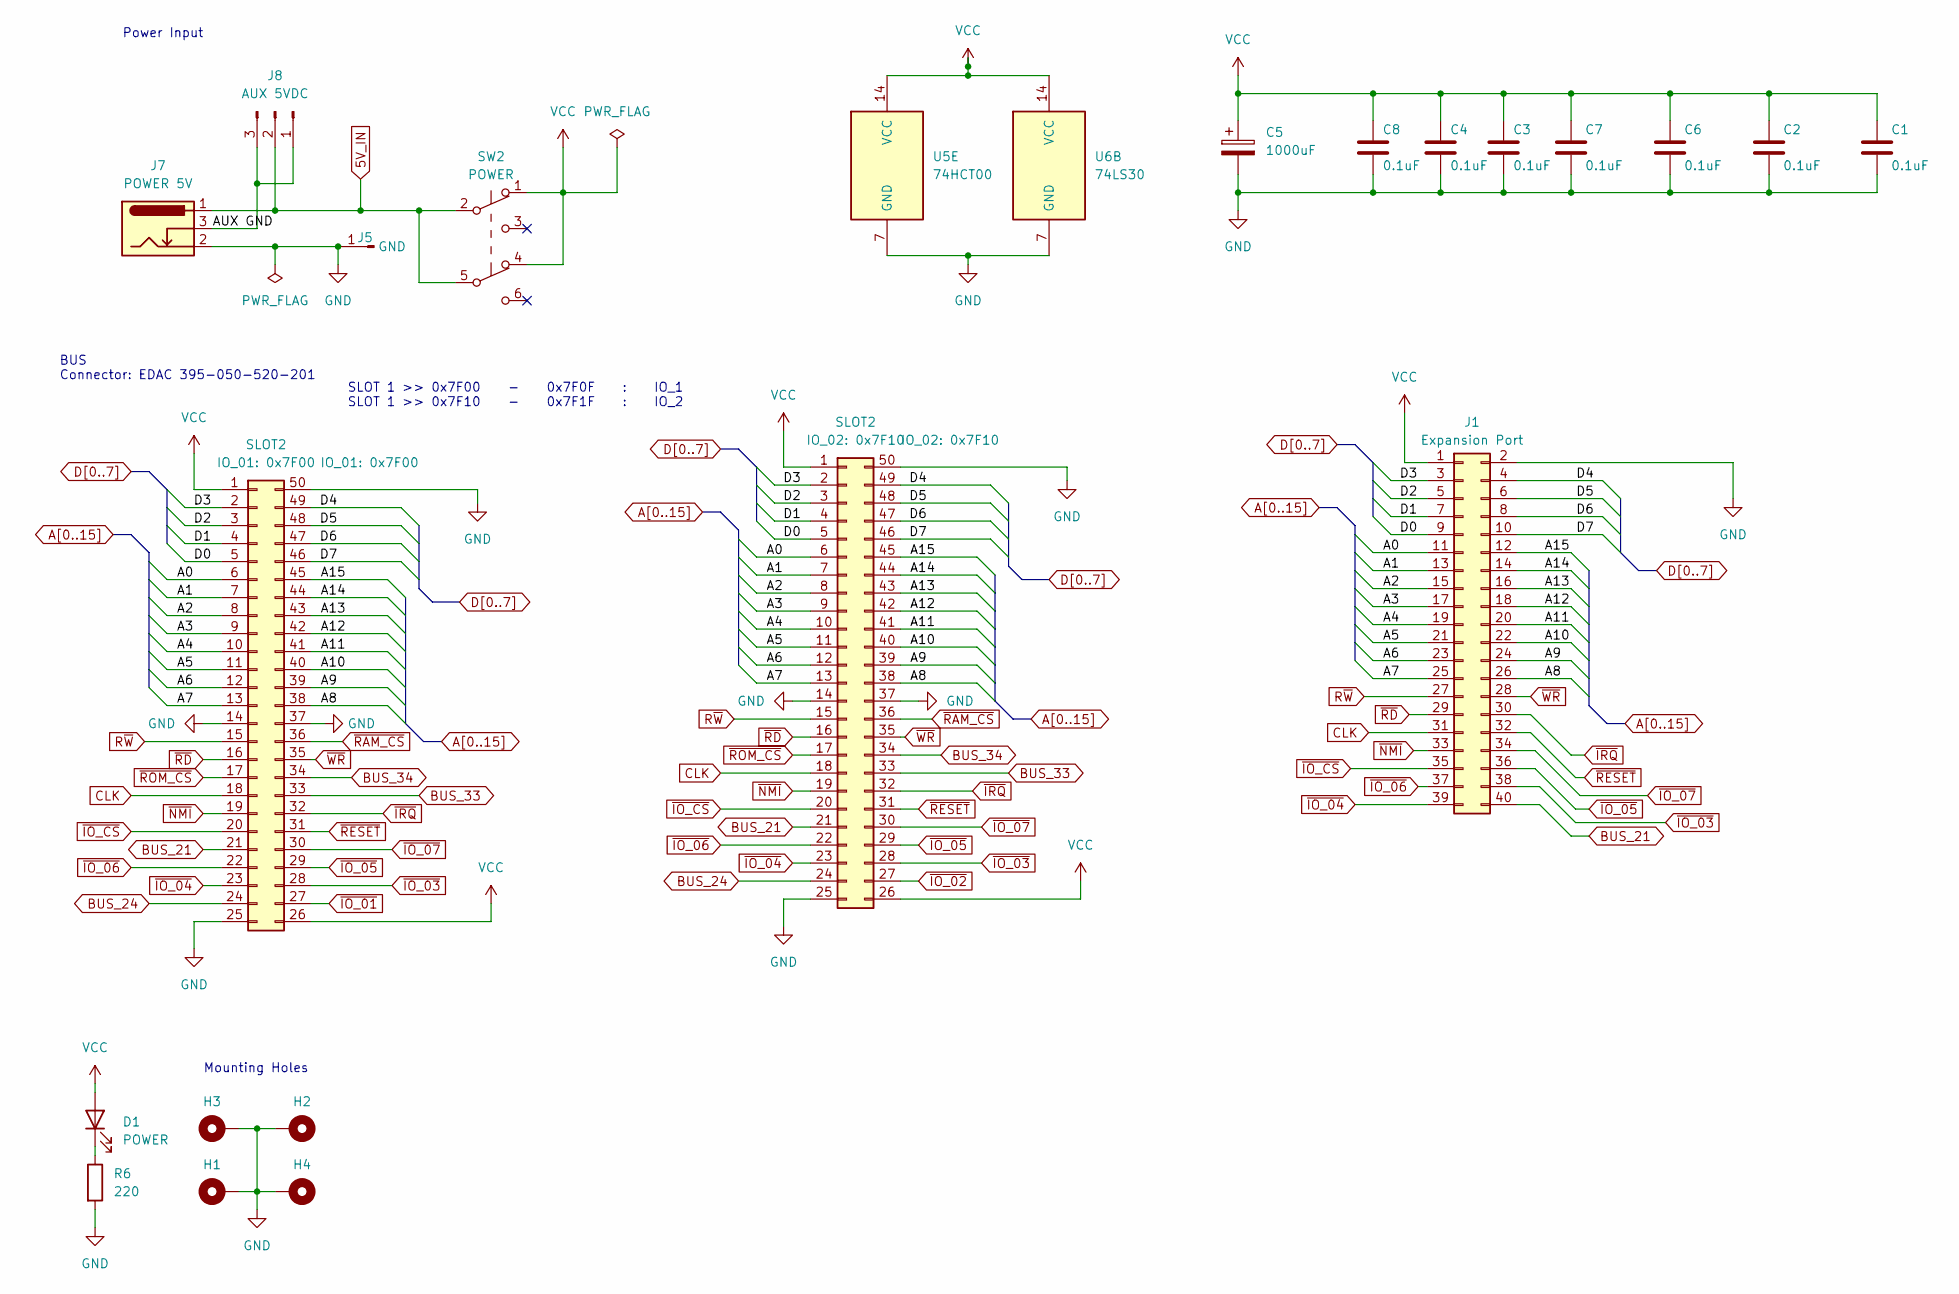
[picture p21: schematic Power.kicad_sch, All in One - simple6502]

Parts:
C1, C2, C3, C4, C6, C7, C8: 0.1uF; C_Disc_D3.0mm_W1.6mm_P2.50mm
C5: 1000uF; CP_Radial_D6.3mm_P2.50mm
D1: POWER; LED_D3.0mm
H1, H2, H3, H4: M; MountingHole_2.7mm_M2.5_Pad_Via
J1: Expansion Port; PinHeader_2x20_P2.54mm_Vertical
J5: GND; PinHeader_1x01_P2.54mm_Vertical
J7: POWER 5V; BarrelJack_Horizontal
J8: AUX 5VDC; PinHeader_1x03_P2.54mm_Vertical
R6: 220; R_Axial_DIN0204_L3.6mm_D1.6mm_P7.62mm_Horizontal
SLOT2: IO_02: 0x7F10; EDAC 395-050-520-201
SW2: POWER; SW_Push_2P2T_Toggle_CK_PVA2OAH5xxxxxxV2
U5: 74HCT00; DIP-14_W7.62mm_Socket
U6: 74LS30; DIP-14_W7.62mm_Socket

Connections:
5V_IN: J7.1, J8.2, SW2.2 (B), SW2.5 (B); also elsewhere on the board
/Power and support/AUX GND: J7.3, J8.1, J8.3
A0: J1.11, SLOT2.6; also elsewhere on the board
A1: J1.13, SLOT2.7; also elsewhere on the board
A2: J1.15, SLOT2.8; also elsewhere on the board
A3: J1.17, SLOT2.9; also elsewhere on the board
A4: J1.19, SLOT2.10; also elsewhere on the board
A5: J1.21, SLOT2.11; also elsewhere on the board
A6: J1.23, SLOT2.12; also elsewhere on the board
A7: J1.25, SLOT2.13; also elsewhere on the board
A8: J1.26, SLOT2.38; also elsewhere on the board
A9: J1.24, SLOT2.39; also elsewhere on the board
A10: J1.22, SLOT2.40; also elsewhere on the board
A11: J1.20, SLOT2.41; also elsewhere on the board
A12: J1.18, SLOT2.42; also elsewhere on the board
A13: J1.16, SLOT2.43; also elsewhere on the board
A14: J1.14, SLOT2.44; also elsewhere on the board
A15: J1.12, SLOT2.45; also elsewhere on the board
BUS_21: J1.40, SLOT2.21; also elsewhere on the board
BUS_24: SLOT2.24; also elsewhere on the board
BUS_33: SLOT2.33; also elsewhere on the board
BUS_34: SLOT2.34; also elsewhere on the board
CLK: J1.31, SLOT2.18; also elsewhere on the board
D0: J1.9, SLOT2.5; also elsewhere on the board
D1: J1.7, SLOT2.4; also elsewhere on the board
D2: J1.5, SLOT2.3; also elsewhere on the board
D3: J1.3, SLOT2.2; also elsewhere on the board
D4: J1.4, SLOT2.49; also elsewhere on the board
D5: J1.6, SLOT2.48; also elsewhere on the board
D6: J1.8, SLOT2.47; also elsewhere on the board
D7: J1.10, SLOT2.46; also elsewhere on the board
GND: C1.2, C2.2, C3.2, C4.2, C5.2, C6.2, C7.2, C8.2, H1.1, H2.1, H3.1, H4.1, J1.2, J5.1, J7.2, R6.2, SLOT2.14, SLOT2.25, SLOT2.37, SLOT2.50, U5.7 (GND), U6.7 (GND); also elsewhere on the board
unnamed: D1.1 (K), R6.1
R~W: J1.27, SLOT2.15; also elsewhere on the board
VCC: C1.1, C2.1, C3.1, C4.1, C5.1, C6.1, C7.1, C8.1, D1.2 (A), J1.1, SLOT2.1, SLOT2.26, SW2.1 (A), SW2.4 (A), U5.14 (VCC), U6.14 (VCC); also elsewhere on the board
~IO_03: J1.38, SLOT2.28; also elsewhere on the board
~IO_04: J1.39, SLOT2.23; also elsewhere on the board
~IO_05: J1.36, SLOT2.29; also elsewhere on the board
~IO_06: J1.37, SLOT2.22; also elsewhere on the board
~IO_07: J1.34, SLOT2.30; also elsewhere on the board
~IO_CS: J1.35, SLOT2.20; also elsewhere on the board
~IRQ: J1.30, SLOT2.32; also elsewhere on the board
~NMI: J1.33, SLOT2.19; also elsewhere on the board
~RAM_CS: SLOT2.36; also elsewhere on the board
~RD: J1.29, SLOT2.16; also elsewhere on the board
~RESET: J1.32, SLOT2.31; also elsewhere on the board
~ROM_CS: SLOT2.17; also elsewhere on the board
~WR: J1.28, SLOT2.35; also elsewhere on the board

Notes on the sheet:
Power Input
SLOT 1 >> 0x7F00 - 0x7F0F : IO_1 SLOT 1 >> 0x7F10 - 0x7F1F : IO_2
BUS Connector: EDAC 395-050-520-201
Mounting Holes

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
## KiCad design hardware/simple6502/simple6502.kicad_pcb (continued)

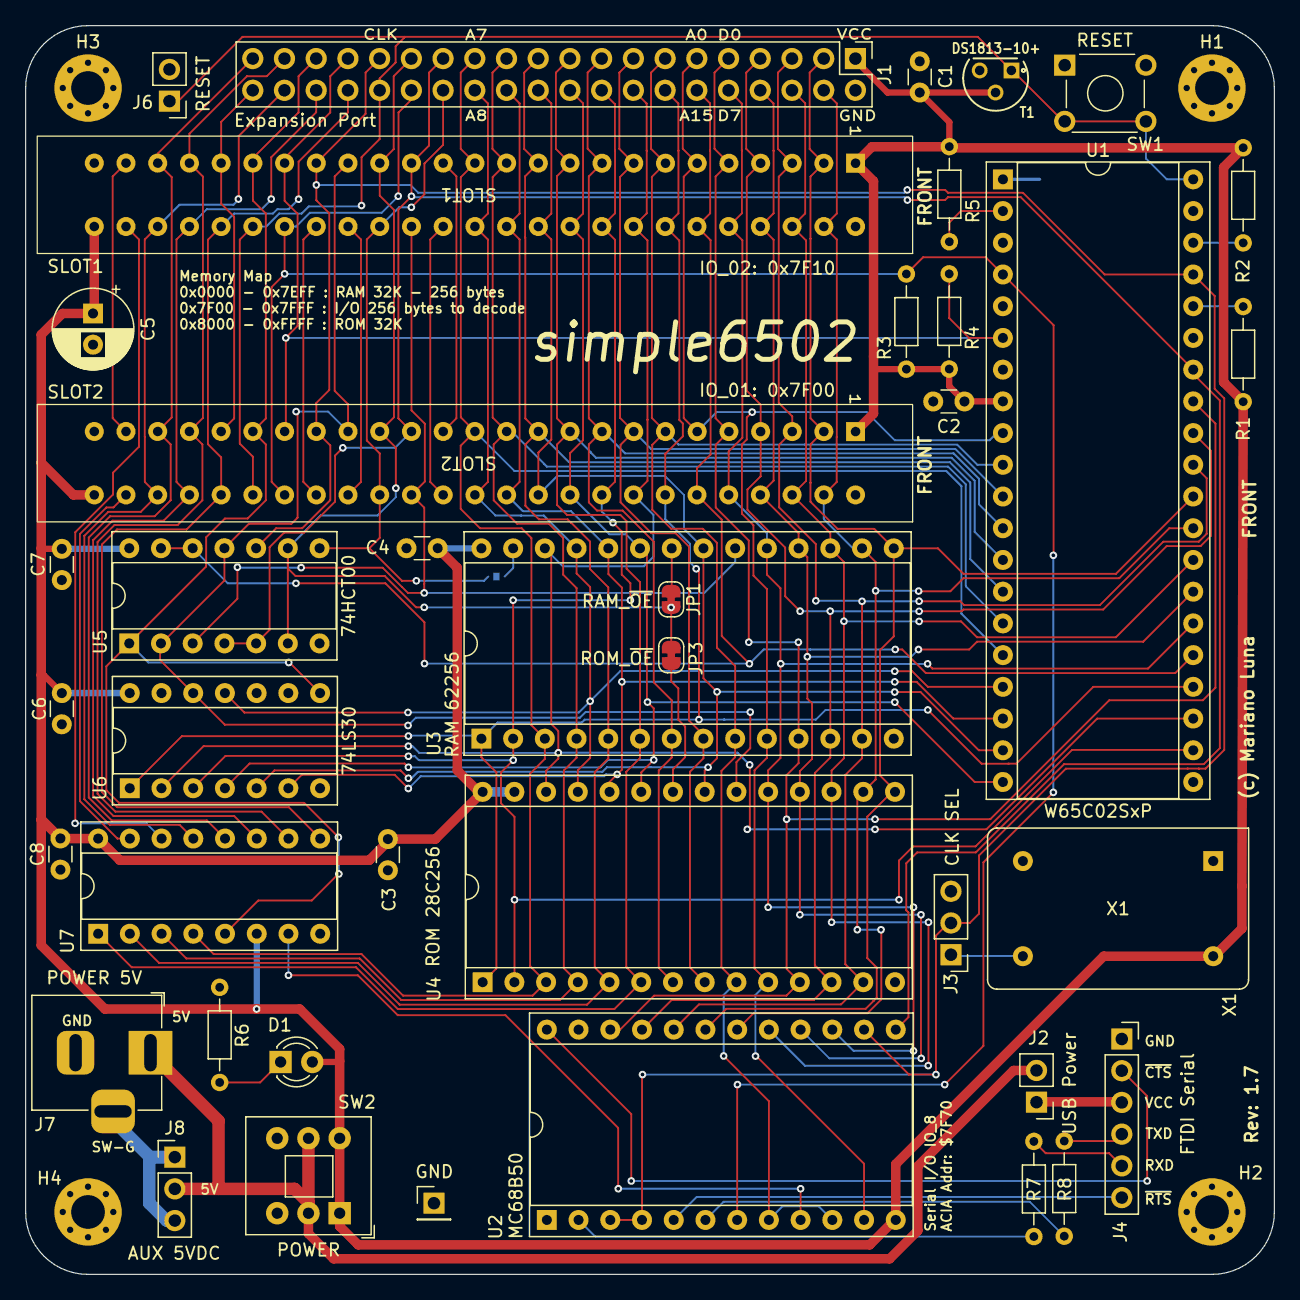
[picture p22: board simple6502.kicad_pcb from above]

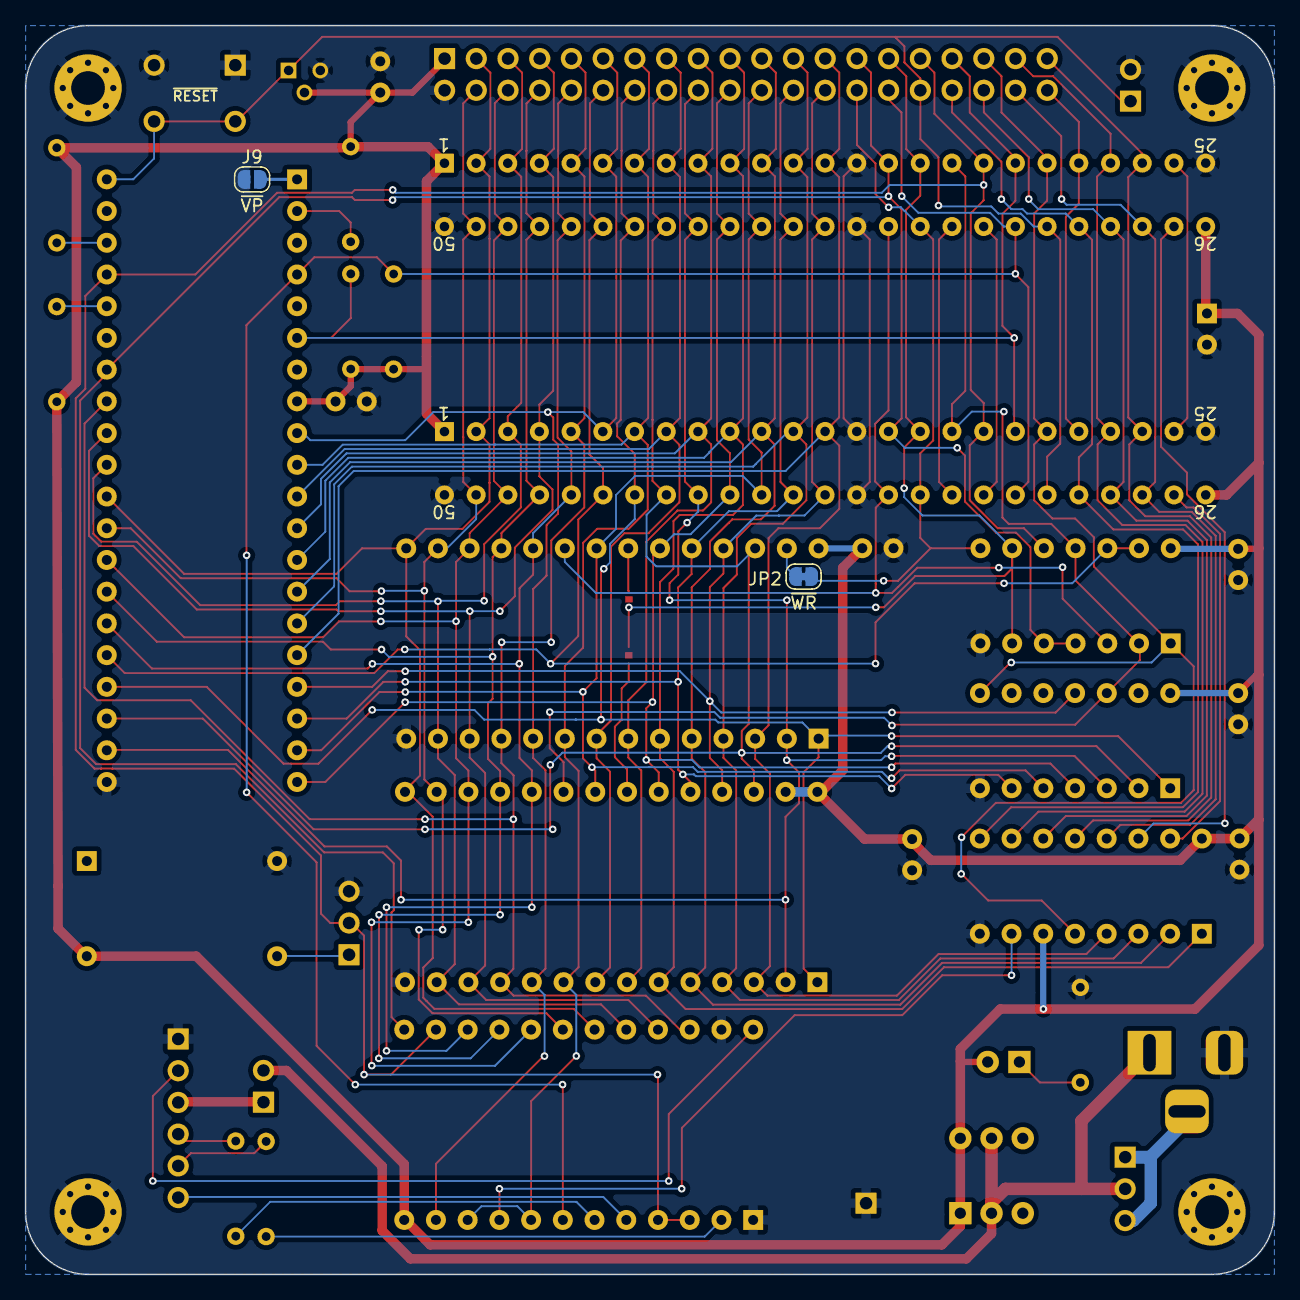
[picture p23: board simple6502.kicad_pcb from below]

Board: 2 copper layers, 100.0 x 100.0 mm, 46 parts (2 on the bottom side), 66 nets.

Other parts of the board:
SLOT1: IO_02: 0x7F10; EDAC 395-050-520-201

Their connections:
A0: SLOT1.6; also elsewhere on the board
A1: SLOT1.7; also elsewhere on the board
A2: SLOT1.8; also elsewhere on the board
A3: SLOT1.9; also elsewhere on the board
A4: SLOT1.10; also elsewhere on the board
A5: SLOT1.11; also elsewhere on the board
A6: SLOT1.12; also elsewhere on the board
A7: SLOT1.13; also elsewhere on the board
A8: SLOT1.38; also elsewhere on the board
A9: SLOT1.39; also elsewhere on the board
A10: SLOT1.40; also elsewhere on the board
A11: SLOT1.41; also elsewhere on the board
A12: SLOT1.42; also elsewhere on the board
A13: SLOT1.43; also elsewhere on the board
A14: SLOT1.44; also elsewhere on the board
A15: SLOT1.45; also elsewhere on the board
BUS_21: SLOT1.21; also elsewhere on the board
BUS_24: SLOT1.24; also elsewhere on the board
BUS_33: SLOT1.33; also elsewhere on the board
BUS_34: SLOT1.34; also elsewhere on the board
CLK: SLOT1.18; also elsewhere on the board
D0: SLOT1.5; also elsewhere on the board
D1: SLOT1.4; also elsewhere on the board
D2: SLOT1.3; also elsewhere on the board
D3: SLOT1.2; also elsewhere on the board
D4: SLOT1.49; also elsewhere on the board
D5: SLOT1.48; also elsewhere on the board
D6: SLOT1.47; also elsewhere on the board
D7: SLOT1.46; also elsewhere on the board
GND: SLOT1.14, SLOT1.25, SLOT1.37, SLOT1.50; also elsewhere on the board
R~W: SLOT1.15; also elsewhere on the board
VCC: SLOT1.1, SLOT1.26; also elsewhere on the board
~IO_02: SLOT1.27; also elsewhere on the board
~IO_03: SLOT1.28; also elsewhere on the board
~IO_04: SLOT1.23; also elsewhere on the board
~IO_05: SLOT1.29; also elsewhere on the board
~IO_06: SLOT1.22; also elsewhere on the board
~IO_07: SLOT1.30; also elsewhere on the board
~IO_CS: SLOT1.20; also elsewhere on the board
~IRQ: SLOT1.32; also elsewhere on the board
~NMI: SLOT1.19; also elsewhere on the board
~RAM_CS: SLOT1.36; also elsewhere on the board
~RD: SLOT1.16; also elsewhere on the board
~RESET: SLOT1.31; also elsewhere on the board
~ROM_CS: SLOT1.17; also elsewhere on the board
~WR: SLOT1.35; also elsewhere on the board

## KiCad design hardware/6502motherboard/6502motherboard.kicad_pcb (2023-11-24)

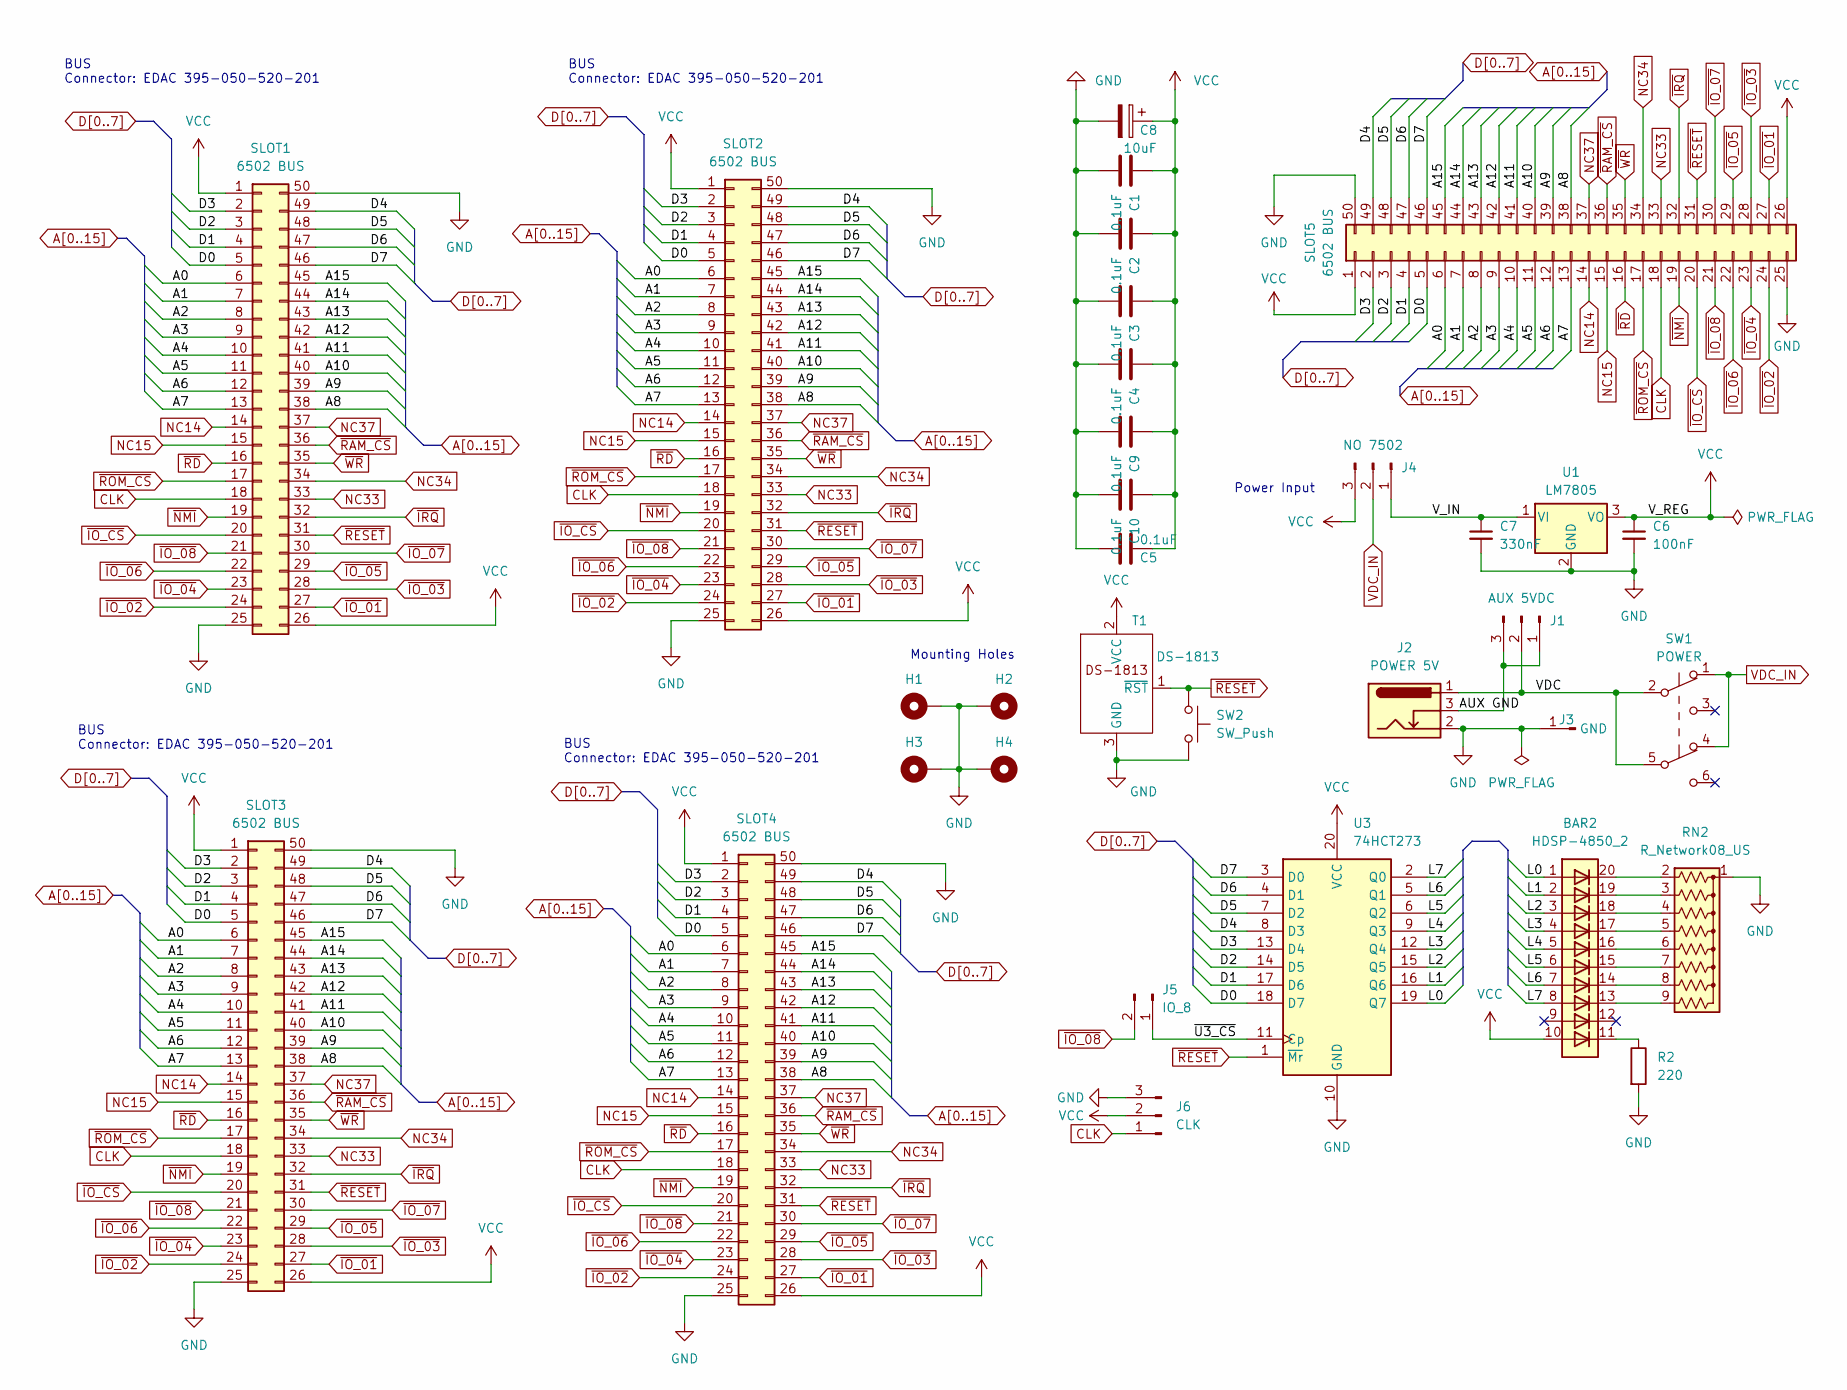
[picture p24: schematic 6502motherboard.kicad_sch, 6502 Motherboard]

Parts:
BAR2: HDSP-4850_2; HDSP-4850
C1, C2, C3, C4, C5, C9, C10: 0.1uF; C_Disc_D3.0mm_W1.6mm_P2.50mm
C6: 100nF; C_Disc_D3.0mm_W1.6mm_P2.50mm
C7: 330nF; C_Disc_D3.0mm_W1.6mm_P2.50mm
C8: 10uF; CP_Radial_D6.3mm_P2.50mm
H1, H2, H3, H4: M; MountingHole_2.7mm_M2.5_Pad_Via
J1: AUX 5VDC; PinHeader_1x03_P2.54mm_Vertical
J2: POWER 5V; BarrelJack_Horizontal
J3: GND; PinHeader_1x01_P2.54mm_Vertical
J4: NO 7502; PinHeader_1x03_P2.54mm_Vertical
J5: IO_8; PinHeader_1x02_P2.54mm_Vertical
J6: CLK; JST_PH_B3B-PH-K_1x03_P2.00mm_Vertical
R2: 220; R_Axial_DIN0204_L3.6mm_D1.6mm_P7.62mm_Horizontal
RN2: R_Network08_US; R_Array_SIP9
SLOT1, SLOT2, SLOT3, SLOT4: 6502 BUS; EDAC 395-050-520-201
SLOT5: 6502 BUS; PinHeader_2x25_P2.54mm_Vertical_Counter_Clockwise
SW1: POWER; SW_Push_2P2T_Toggle_CK_PVA2OAH5xxxxxxV2
SW2: SW_Push; SW_PUSH_6mm_H5mm
T1: DS-1813; 21-0248A_MAXIM
U1: LM7805; TO-220-3_Horizontal_TabDown
U3: 74HCT273; DIP-20_W7.62mm_Socket

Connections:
/AUX GND: J1.1, J1.3, J2.3
/L0: BAR2.1 (A), U3.19 (Q7)
/L1: BAR2.2 (A), U3.16 (Q6)
/L2: BAR2.3 (A), U3.15 (Q5)
/L3: BAR2.4 (A), U3.12 (Q4)
/L4: BAR2.5 (A), U3.9 (Q3)
/L5: BAR2.6 (A), U3.6 (Q2)
/L6: BAR2.7 (A), U3.5 (Q1)
/L7: BAR2.8 (A), U3.2 (Q0)
/VDC: J1.2, J2.1, SW1.2 (B), SW1.5 (B)
/V_IN: C7.1, J4.1, U1.1 (VI)
/~U3_CS: J5.1, U3.11 (Cp)
A0: SLOT1.6, SLOT2.6, SLOT3.6, SLOT4.6, SLOT5.6
A1: SLOT1.7, SLOT2.7, SLOT3.7, SLOT4.7, SLOT5.7
A2: SLOT1.8, SLOT2.8, SLOT3.8, SLOT4.8, SLOT5.8
A3: SLOT1.9, SLOT2.9, SLOT3.9, SLOT4.9, SLOT5.9
A4: SLOT1.10, SLOT2.10, SLOT3.10, SLOT4.10, SLOT5.10
A5: SLOT1.11, SLOT2.11, SLOT3.11, SLOT4.11, SLOT5.11
A6: SLOT1.12, SLOT2.12, SLOT3.12, SLOT4.12, SLOT5.12
A7: SLOT1.13, SLOT2.13, SLOT3.13, SLOT4.13, SLOT5.13
A8: SLOT1.38, SLOT2.38, SLOT3.38, SLOT4.38, SLOT5.38
A9: SLOT1.39, SLOT2.39, SLOT3.39, SLOT4.39, SLOT5.39
A10: SLOT1.40, SLOT2.40, SLOT3.40, SLOT4.40, SLOT5.40
A11: SLOT1.41, SLOT2.41, SLOT3.41, SLOT4.41, SLOT5.41
A12: SLOT1.42, SLOT2.42, SLOT3.42, SLOT4.42, SLOT5.42
A13: SLOT1.43, SLOT2.43, SLOT3.43, SLOT4.43, SLOT5.43
A14: SLOT1.44, SLOT2.44, SLOT3.44, SLOT4.44, SLOT5.44
A15: SLOT1.45, SLOT2.45, SLOT3.45, SLOT4.45, SLOT5.45
CLK: J6.1, SLOT1.18, SLOT2.18, SLOT3.18, SLOT4.18, SLOT5.18
D0: SLOT1.5, SLOT2.5, SLOT3.5, SLOT4.5, SLOT5.5, U3.18 (D7)
D1: SLOT1.4, SLOT2.4, SLOT3.4, SLOT4.4, SLOT5.4, U3.17 (D6)
D2: SLOT1.3, SLOT2.3, SLOT3.3, SLOT4.3, SLOT5.3, U3.14 (D5)
D3: SLOT1.2, SLOT2.2, SLOT3.2, SLOT4.2, SLOT5.2, U3.13 (D4)
D4: SLOT1.49, SLOT2.49, SLOT3.49, SLOT4.49, SLOT5.49, U3.8 (D3)
D5: SLOT1.48, SLOT2.48, SLOT3.48, SLOT4.48, SLOT5.48, U3.7 (D2)
D6: SLOT1.47, SLOT2.47, SLOT3.47, SLOT4.47, SLOT5.47, U3.4 (D1)
D7: SLOT1.46, SLOT2.46, SLOT3.46, SLOT4.46, SLOT5.46, U3.3 (D0)
GND: C1.2, C2.2, C3.2, C4.2, C5.2, C6.2, C7.2, C8.2, C9.2, C10.2, H1.1, H2.1, H3.1, H4.1, J2.2, J3.1, J6.3, R2.2, RN2.1 (common), SLOT1.25, SLOT1.50, SLOT2.25, SLOT2.50, SLOT3.25, SLOT3.50, SLOT4.25, SLOT4.50, SLOT5.25, SLOT5.50, SW2.2, T1.3 (GND), U1.2 (GND), U3.10 (GND)
NC14: SLOT1.14, SLOT2.14, SLOT3.14, SLOT4.14, SLOT5.14
NC15: SLOT1.15, SLOT2.15, SLOT3.15, SLOT4.15, SLOT5.15
NC33: SLOT1.33, SLOT2.33, SLOT3.33, SLOT4.33, SLOT5.33
NC34: SLOT1.34, SLOT2.34, SLOT3.34, SLOT4.34, SLOT5.34
NC37: SLOT1.37, SLOT2.37, SLOT3.37, SLOT4.37, SLOT5.37
unnamed: BAR2.11 (K), R2.1
unnamed: BAR2.20 (K), RN2.2 (R1)
unnamed: BAR2.19 (K), RN2.3 (R2)
unnamed: BAR2.18 (K), RN2.4 (R3)
unnamed: BAR2.17 (K), RN2.5 (R4)
unnamed: BAR2.16 (K), RN2.6 (R5)
unnamed: BAR2.15 (K), RN2.7 (R6)
unnamed: BAR2.14 (K), RN2.8 (R7)
unnamed: BAR2.13 (K), RN2.9 (R8)
VCC: BAR2.10 (A), C1.1, C2.1, C3.1, C4.1, C5.1, C6.1, C8.1, C9.1, C10.1, J4.3, J6.2, SLOT1.1, SLOT1.26, SLOT2.1, SLOT2.26, SLOT3.1, SLOT3.26, SLOT4.1, SLOT4.26, SLOT5.1, SLOT5.26, T1.2 (VCC), U1.3 (VO), U3.20 (VCC)
VDC_IN: J4.2, SW1.1 (A), SW1.4 (A)
~IO_01: SLOT1.27, SLOT2.27, SLOT3.27, SLOT4.27, SLOT5.27
~IO_02: SLOT1.24, SLOT2.24, SLOT3.24, SLOT4.24, SLOT5.24
~IO_03: SLOT1.28, SLOT2.28, SLOT3.28, SLOT4.28, SLOT5.28
~IO_04: SLOT1.23, SLOT2.23, SLOT3.23, SLOT4.23, SLOT5.23
~IO_05: SLOT1.29, SLOT2.29, SLOT3.29, SLOT4.29, SLOT5.29
~IO_06: SLOT1.22, SLOT2.22, SLOT3.22, SLOT4.22, SLOT5.22
~IO_07: SLOT1.30, SLOT2.30, SLOT3.30, SLOT4.30, SLOT5.30
~IO_08: J5.2, SLOT1.21, SLOT2.21, SLOT3.21, SLOT4.21, SLOT5.21
~IO_CS: SLOT1.20, SLOT2.20, SLOT3.20, SLOT4.20, SLOT5.20
~IRQ: SLOT1.32, SLOT2.32, SLOT3.32, SLOT4.32, SLOT5.32
~NMI: SLOT1.19, SLOT2.19, SLOT3.19, SLOT4.19, SLOT5.19
~RAM_CS: SLOT1.36, SLOT2.36, SLOT3.36, SLOT4.36, SLOT5.36
~RD: SLOT1.16, SLOT2.16, SLOT3.16, SLOT4.16, SLOT5.16
~RESET: SLOT1.31, SLOT2.31, SLOT3.31, SLOT4.31, SLOT5.31, SW2.1, T1.1 (~RST), U3.1 (~Mr)
~ROM_CS: SLOT1.17, SLOT2.17, SLOT3.17, SLOT4.17, SLOT5.17
~WR: SLOT1.35, SLOT2.35, SLOT3.35, SLOT4.35, SLOT5.35

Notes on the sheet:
Mounting Holes
Power Input
BUS Connector: EDAC 395-050-520-201

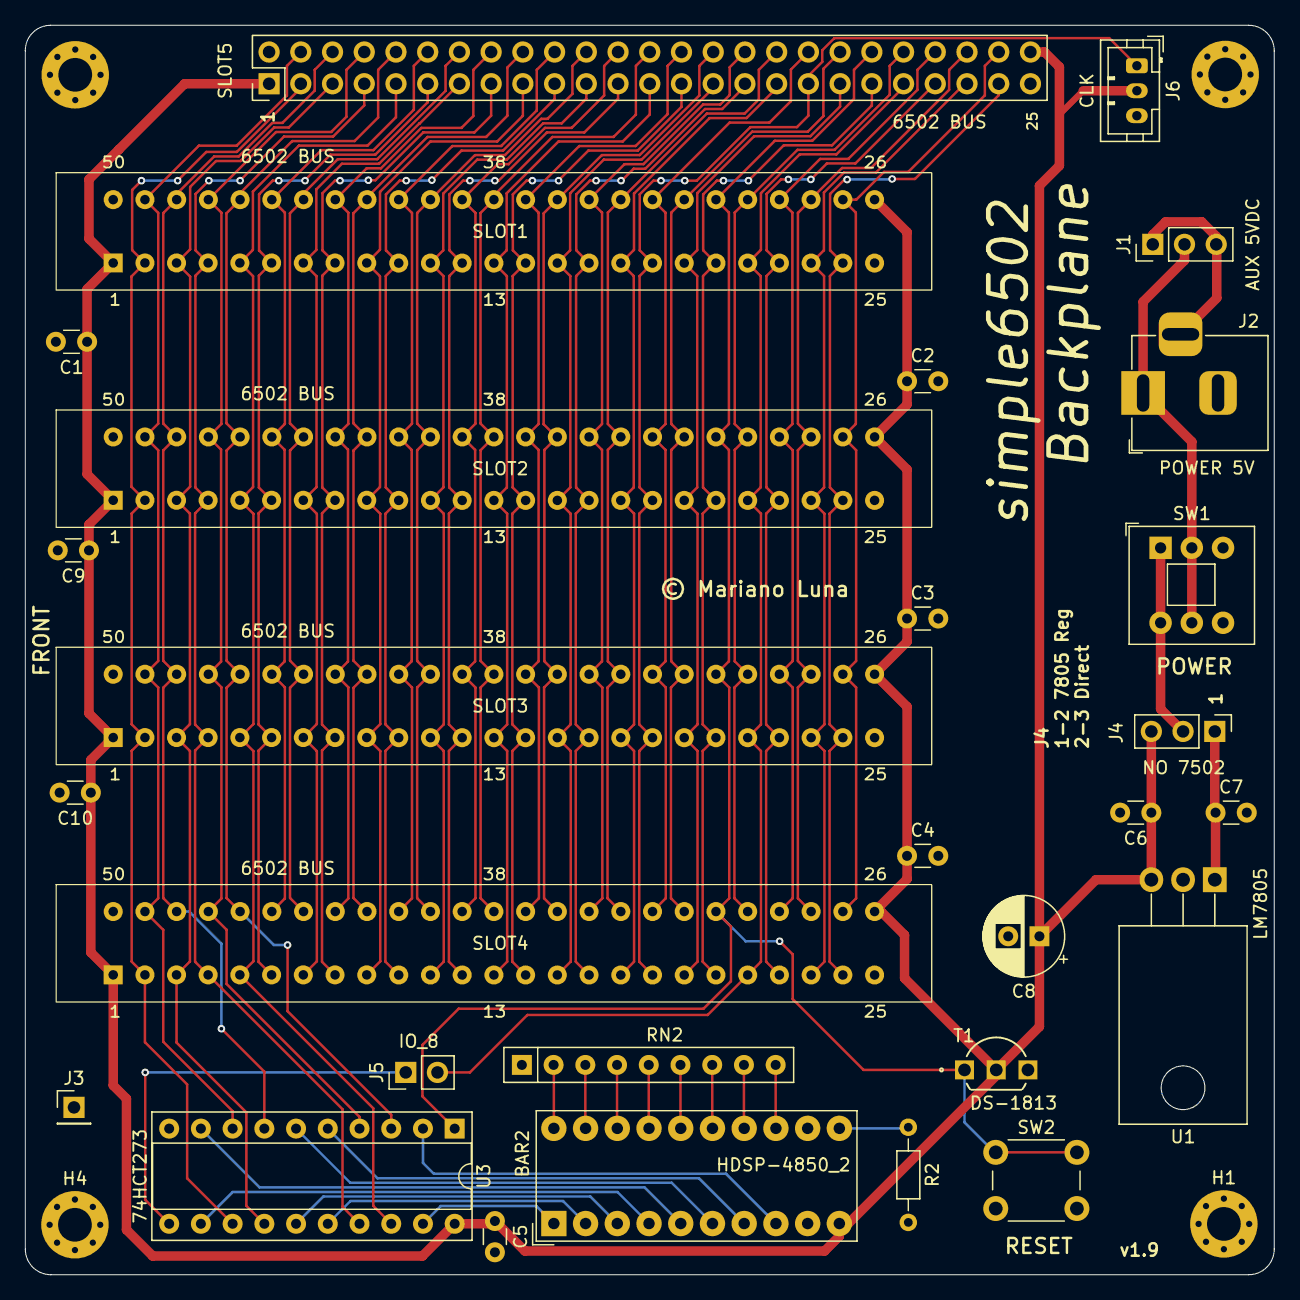
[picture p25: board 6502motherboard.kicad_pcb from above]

Board: 2 copper layers, 100.0 x 100.0 mm, 33 parts (0 on the bottom side), 70 nets.

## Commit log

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2023-09-21 Kicad project added + standard structure
    [simple6502.kicad_pcb, simple6502.kicad_sch]
2023-09-22 Kicad 7 update, 6502 libraries, moved datasheets to their own folder
    [simple6502.kicad_sch]
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2023-09-22 Wired CPU, RAM and ROM
    [simple6502.kicad_sch]
2023-09-22 Reset, Clock, Expansion and Power
    [Power.kicad_sch, simple6502.kicad_sch]
2023-09-22 Fixed Bus label names
    [Power.kicad_sch, simple6502.kicad_sch]
2023-09-22 Memory decoder v1
    [Power.kicad_sch, simple6502.kicad_sch]
2023-09-22 Main board schematic complete v0.0.1
    [Power.kicad_sch, simple6502.kicad_sch]
2023-09-22 Footprint round 1
    [Power.kicad_sch, simple6502.kicad_sch]
2023-09-23 Added Apple II connector footprint and 3d model
    [simple6502.kicad_sch]
2023-09-23 v0.5 Schematic complete and footprint assigned.
    [Power.kicad_sch, simple6502.kicad_sch]
2023-09-23 PCB defaults set and components dropped
    [Power.kicad_sch, simple6502.kicad_pcb, simple6502.kicad_sch]
2023-09-23 First PCB Layout
    [simple6502.kicad_pcb, simple6502.kicad_sch]
2023-09-23 Fixed Apple Connector 3D model, routing started
    [Power.kicad_sch, simple6502.kicad_pcb]
2023-09-24 Routing PCB
    [simple6502.kicad_pcb]
2023-09-24 More PCB Routing
    [simple6502.kicad_pcb]
2023-09-24 Much More PCB Routing - Clean DRC
    [simple6502.kicad_pcb]
2023-09-24 Mostly done, Address and Data finished
    [simple6502.kicad_pcb]
2023-09-25 rearange the bus for better routing
    [Power.kicad_sch, simple6502.kicad_pcb]
2023-09-25 PCB fully routed clean DRC
    [simple6502.kicad_pcb, simple6502.kicad_sch]
2023-09-25 added IO 3-8 decoder
    [simple6502.kicad_pcb, simple6502.kicad_sch]
2023-09-26 more pin rearrangment in bus connector
    [Power.kicad_sch, simple6502.kicad_pcb, simple6502.kicad_sch]
2023-09-26 Routing v1 finished - DRC passed
    [Power.kicad_sch, simple6502.kicad_pcb]
2023-09-26 Schematics updated to v1 - ERC passed
    [Power.kicad_sch, simple6502.kicad_pcb, simple6502.kicad_sch]
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2023-10-01 Relocated reset
    [Power.kicad_sch, simple6502.kicad_pcb, simple6502.kicad_sch]
2023-10-02 adding Debug leds in IO_8
    [Power.kicad_sch, simple6502.kicad_pcb, simple6502.kicad_sch]
2023-10-02 version 1.1
    [simple6502.kicad_pcb]
2023-10-14 flush changes
    [protoCard.kicad_pcb, protoCard.kicad_sch]
2023-10-15 clean pcb board style
    [Power.kicad_sch, simple6502.kicad_pcb]
2023-10-16 cpu board only ready
    [Power.kicad_sch, simple6502.kicad_pcb, simple6502.kicad_sch]
2023-10-16 cpu board 1.0 PCB ready
    [simple6502.kicad_pcb, simple6502.kicad_sch]
2023-10-17 cpu board 1.0 PCB minor routing tidy up
    [simple6502.kicad_pcb]
2023-10-17 adding schematic pdf and board images
    [Power.kicad_sch, simple6502.kicad_sch]
2023-10-17 CPU Board v1.2 complete
    [Power.kicad_sch, simple6502.kicad_sch]
2023-10-17 Protoboard v0.5
    [protoCard.kicad_pcb]
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2023-10-17 Fixed 6502 Pinout, routed bus and power
    [6502motherboard.kicad_pcb, 6502motherboard.kicad_sch]
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2023-10-26 v1.5 CPU Board Complete
    [Power.kicad_sch, simple6502.kicad_pcb, simple6502.kicad_sch]
2023-11-04 Motherboard added 7805 regulator
    [6502motherboard.kicad_pcb, 6502motherboard.kicad_sch]
2023-11-04 Schematic and PCB cleanup
    [simple6502.kicad_pcb, simple6502.kicad_sch]
2023-11-04 I_O8 Jumper and more PCB cleanup
    [6502motherboard.kicad_pcb, 6502motherboard.kicad_sch]
2023-11-14 rev 1.8 new pcb optimized power routing
    [6502motherboard.kicad_pcb, 6502motherboard.kicad_sch, simple6502.kicad_pcb]
2023-11-24 rev 1.8.1 pcb routed external connector in top layer
    [6502motherboard.kicad_pcb]
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2023-11-24 Schematic rev 1.6 complete
    [Power.kicad_sch, simple6502.kicad_pcb, simple6502.kicad_sch]
2024-03-07 cleanup and minor changes
    [protoCard.kicad_pcb, simple6502.kicad_pcb]
2024-06-27 Squashed commit of the following:
    commit 7c3efda86e123a872d37b7a0967bfebff1f0e87c
    Author: Mariano Luna <marianolu@gmail.com>
    Date: Wed Jun 26 21:29:25 2024 -0500
    added license to the read me
    commit 04e24ff3751ecfd7aa1644195e6f678569023e69
    Author: Mariano Luna <marianolu@gmail.com>
    Date: Wed Jun 26 21:19:54 2024 -0500
    typo fix for {\textunderscore}
    commit 2b909ce419fda75b2b3b71af0dca9a0f271ced5f
    Author: Mariano Luna <marianolu@gmail.com>
    Date: Wed Jun 26 21:10:17 2024 -0500
    updated ReadME and memory map in the schematic
    commit 245ee8cf40a99742bf88408506d7aad409daa5ea
    Author: Mariano Luna <marianolu@gmail.com>
    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
    [5.8x5.8mmSWITCH.STEP, Power.kicad_sch, simple6502.kicad_pcb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]
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2024-06-27 fixed pinout + power led
    [protoCard.kicad_pcb, protoCard.kicad_sch]
2024-06-27 Protoboard Rev 1.2
    Fixed pinout of connector and added power led
    [protoCard.kicad_pcb, protoCard.kicad_sch]
2024-07-03 Version 1.6 Final
    Added solder pads just in case
    [Power.kicad_sch, simple6502.kicad_pcb, simple6502.kicad_sch]
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2024-07-17 Revision 1.6.1 Moved C5 and added C8
    Moved C5 to make space for a slim ZIF for the ROM.
    [Power.kicad_sch, simple6502.kicad_pcb, simple6502.kicad_sch]
2024-07-17 Rev. 1.6.1 Silkscreen and labels
    Added labels fro the FTDI, moved some other that got covered by sockets.
    [simple6502.kicad_pcb]
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2024-07-20 firmware dev environment and config
    [simple6502.cfg]
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2024-07-22 PCB Rev 1.7 - rewire FTDI
    using a more standard pinout for the FTDI header
    [Power.kicad_sch, simple6502.kicad_pcb, simple6502.kicad_sch]
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2024-07-23 IO Card Initial commit
    VIA 6522 IO card and other goodies
    [IO_Card.kicad_pcb, IO_Card.kicad_sch]
2024-07-23 flipped card PCB to face the correct way
    [IO_Card.kicad_pcb]
2024-07-23 Rev: 0.5 basic VIA wiring
    [IO_Card.kicad_pcb, IO_Card.kicad_sch]
2024-07-23 Rev 0.6 2 VIAs ready to route
    [IO_Card.kicad_pcb, IO_Card.kicad_sch]
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2024-07-29 new USR program config to assemble for running in memory
    [simple6502_RAM-Only.cfg]
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2024-08-01 IO Card is Rev 1.0 PCB complete
    [IO_Card.kicad_pcb]
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2024-08-07 IOCard with SMD bypass caps
    [IO_Card.kicad_pcb, IO_Card.kicad_sch]
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2024-08-17 IO Card rev 1.1 + smd caps
    [IO_Card.kicad_pcb, IO_Card.kicad_sch]
2026-04-23 working files to sync
    [simple6502.kicad_pcb]
2026-07-01 Updated to Kicad 10 - IO Card added a PS2 port
    multiple model and footprint updates
    PS/2 via PIC added to the IO card
    Project updated to Kicad 10
    [5.8x5.8mmSWITCH.STEP, 6502_PS2_Keyboard.kicad_pcb, 6502_PS2_Keyboard.kicad_sch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]
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2026-07-01 IO Card passing DRC
    [IO_Card.kicad_pcb]
2026-10-26 firmware: add Intel HEX LOAD/SAVE over serial (v0.2.0)
    Add L (load) and S (save) monitor commands backed by new BIOS routines
    load_ihex and save_ihex. Record addresses are carried in the Intel HEX
    stream so no manual deposit address is needed, and each record's checksum
    is verified on load (CKSUM ERR on mismatch, OK on EOF).
    WozMon's per-letter command compares are replaced by a single JSR to a
    new BIOS cmd_dispatch routine that decodes R/L/S. This moves the logic
    out of the tight MONITOR segment (freeing ~10 bytes) and lets the
    routines be reused from other code.
    save_ihex seeds its start from WozMon's STL/STH (block-XAM leaves the
    start there) and emits 16-byte data records plus an EOF r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
2026-10-26 firmware: add fixed-address BIOS jump table (ABI) v0.4.0
    Expose BIOS routines through a fixed jump table at the start of ROM ($8000),
    KERNAL-style, so external programs call stable addresses that survive BIOS
    rebuilds. Seven entries to start: cold start, monitor, and the serial
    routines. The table is append-only.
    Add bios_jumptable.inc with public BIOS_* address equates, and switch
    userprg.s to call through it instead of hardcoded (stale) addresses.
    Document the ABI in the README and changelog; bump BIOS to 0.4.0.
2026-10-27 firmware: implement POST memory tests (v0.5.0)
    Add a Power-On Self Test:
    - ZP and Stack (Page 1) checkerboard test ($55/$AA) run in the reset
    vector before the stack is used, so Page 1 is tested without clobbering
    a live return address.
    - RAM walk from $0200 up, stopping at the I/O boundary ($7F00) so it never
    writes hardware registers; detected top of RAM stored in RAM_SIZE.
    - post_fail fault beacon: drives a ~1 kHz pattern on data bit D0 via repeated
    ZP writes (no serial/indicator available yet in rev 1.6), probe-observable.
    Placeholder until a real failure indicator is designed.
    Reserve TOCKS as a 3-byte jiffy counter and POST_PTR in the ZP map; the VIA
    Timer 1 tick remains a s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
2026-10-28 firmware: wire ZP/stack POST test into reset vector (v0.6.1)
    The ZP and Stack (Page 1) checkerboard test was described in the 0.5.0 docs
    but never added to the reset vector, so post_fail was unreachable. Add the
    test before the stack is first used and branch to post_fail on mismatch.
    post_fail now sits just before post so all four checks reach it directly.
    Verified in the emulator: normal boot unchanged; a deliberately broken stack
    compare hangs in post_fail with SP still at its reset value.
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2026-10-30 firmware: BASIC entries and LOAD/SAVE stubs in the jump table (v0.8.0)
    Append jump table slots 8 to 11: BIOS_BASIC_COLD ($8018) and BIOS_BASIC_WARM
    ($801B) jump to BASIC's cold and warm start at $DC00 and $DC03, BIOS_LOAD
    ($801E) and BIOS_SAVE ($8021) call new bios_load and bios_save stubs (just
    RTS). Slots 0 to 7 did not move.
    Move the jump table from BIOS.s into its own file, bios_header.s. The linker
    checks every slot against bios_jumptable.inc, and BASIC's header.s checks
    that its entry points are where the BIOS jumps, so a mismatch fails the build.
    BASIC's LOAD and SAVE now jump to the BIOS slots instead of having their own
    rts. The BASIC binary grew 5 bytes and its reference binary w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
2026-11-01 firmware: BIOS_GET_TOCKS, machine config byte, IRQ saves X/Y (v0.10.0)
    TOCKS jiffy clock: verified in the emulator now that it delivers VIA
    interrupts (counts through the monitor, Intel HEX load/save and BASIC; one
    tick is ~18,500 cycles, 10 ms within the 1% the measurement resolves). The
    stale POST stub is removed. via_init clears TOCKS before it looks for the
    VIA, so without the I/O card it reads 0 instead of the $AA the memory tests
    leave in zero page.
    irq_handler saves A, X and Y on entry and restores them before the RTI, so
    the sources added to it later can use any register. Checked with a test
    handler that trashes X and Y: intact with the save, broken without it.
    New jump table slot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
2026-11-02 basic: fix TAB, POS and comma zones, v0.1.1
    POSX stayed at 13 (CRLF_1) after every line break, so TAB(n) printed no
    spaces, POS(0) returned 13 and the comma zones were off. CRDO stores CRLF_1 in
    POSX and PRINTNULLS is supposed to clear it. Upstream does that with
    lda #0 / sta POSX unless CONFIG_2 is set, and with CONFIG_2 either a KERNAL
    keeps POSX (CBM2) or the NULL code clears it. This build is CONFIG_2A with
    neither, so nothing cleared it. PRINTNULLS now sets POSX to 0 (4 bytes).
    Bump BASIC to 0.1.1: the changelog's Unreleased section becomes [0.1.1] with
    the repeated subsections merged, and the README shows the version. The
    reference binary is rebuilt for the change.
    Checked in the emu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
2026-11-02 firmware: VIA1 port helper routines
    Add via_init_ports (set DDRA, DDRB or both from a mode in A, masks in X and
    Y, carry set on an invalid mode), via_write_a, via_write_b, via_read_a and
    via_read_b. They are not in the jump table yet.
    Fix the VIA register names (VIA1_DDRA/DDRB/PORTA/PORTB, the build failed on
    VIA_*) and the copied comments that said PORT A for port B.
    Assembled and the opcodes, register addresses and branch targets were checked
    in the listing. Not run: nothing calls the routines yet.
2026-11-02 firmware: v0.10.2, typo fixes, ENTROPY points at BIOS_GET_TOCKS
    Bump the BIOS to 0.10.2 for the VIA port helpers.
    Fix typos in comments in BIOS.s, wozmon_sbc.s, defines_simple6502.s and
    userprog/userprg.s, including the part number in the WozMon header (MC60B50
    is MC68B50) and the ACIA_TDRE comment. The serial transmit loop label is now
    poll_acia (it was pool_acia). The ROM differs from the previous build only in
    the version digit.
    BASIC: ENTROPY in defines_basic.s now points at BIOS_GET_TOCKS, the planned
    source for the RND seed. Not wired into RND yet (todo in the file), the BASIC
    binary is unchanged.
2026-11-02 firmware: public VIA port routines in the jump table (v0.11.0)
    Add four VIA port routines as jump table slots 13 to 16: BIOS_VIA_CONFIG
    ($8027), BIOS_VIA_SET_DDR ($802A), BIOS_VIA_READ ($802D) and BIOS_VIA_WRITE
    ($8030). One convention for all: X = VIA index (0 = VIA1), Y = port (0 = A,
    1 = B), A = DDR pattern or data. Carry is the result, clear = done, set =
    failed. They fail and do nothing if the VIA was not found at boot (its
    MACHINE_CONFIG bit), the index is unknown, or the port is not 0 or 1. A, X and
    Y come back unchanged. This replaces the internal helpers from 0.10.2.
    VIA_COUNT in defines_simple6502.s: only VIA1 exists for now, so index 1 and up
    fail until VIA2 has an address. The l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
2026-11-02 firmware: add sim65 tests for the BIOS routines
    Add firmware/test: tests of the BIOS routines that run in sim65, cc65's
    simulator, in seconds and with no emulator or board.
    run_tests.sh builds BIOS.s in a temporary folder (out/ is not touched), runs
    every *_test.s and prints the line of the check that failed. A routine that
    never returns is reported as a failure, and a test that repeats a check number
    is rejected. TEST_ROM runs the tests against a ROM image you already have.
    test.inc has the shared helpers. via_ports_test.s calls BIOS_VIA_CONFIG,
    BIOS_VIA_SET_DDR, BIOS_VIA_READ and BIOS_VIA_WRITE through the jump table of
    the real ROM (55 checks): carry result, A/X/Y kept, the right regist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
